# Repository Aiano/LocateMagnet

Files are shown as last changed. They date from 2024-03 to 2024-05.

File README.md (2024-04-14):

# 磁定位系统 LocateMagnet

## 简介

	这个项目来源于一个课设，要求使用AMR磁传感器对小磁铁进行三维空间定位，定位范围1cm x 1cm x 1cm，定位精度要求达到0.1mm。

	本项目采用了5x5 AMR磁传感器阵列，在远超课设要求的范围下，同时满足精度要求，此外还能实时检测，画出移动轨迹。

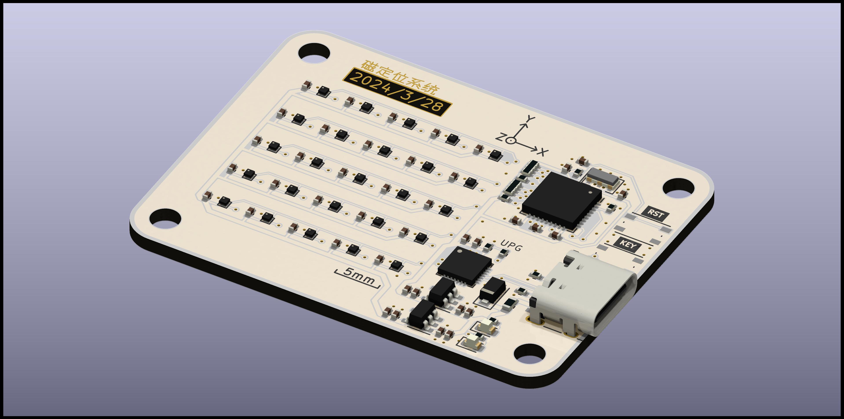
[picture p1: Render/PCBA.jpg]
PCBA


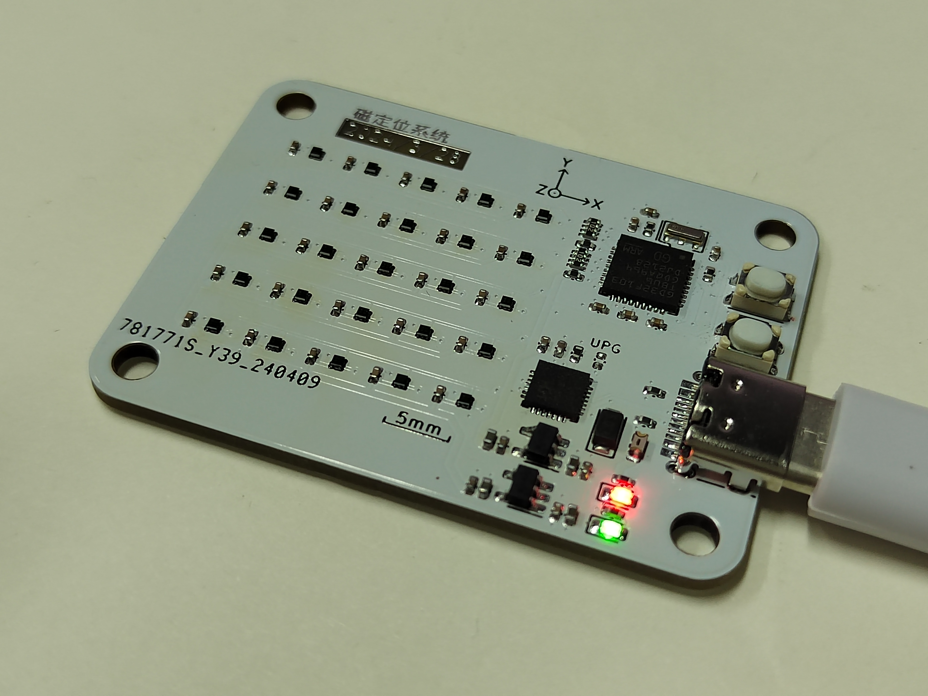
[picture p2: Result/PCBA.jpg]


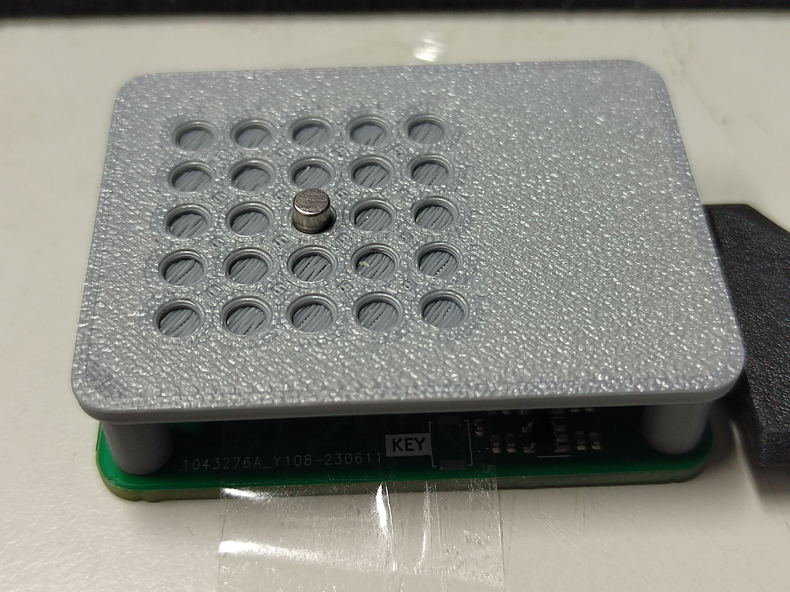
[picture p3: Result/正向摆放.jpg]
正向摆放


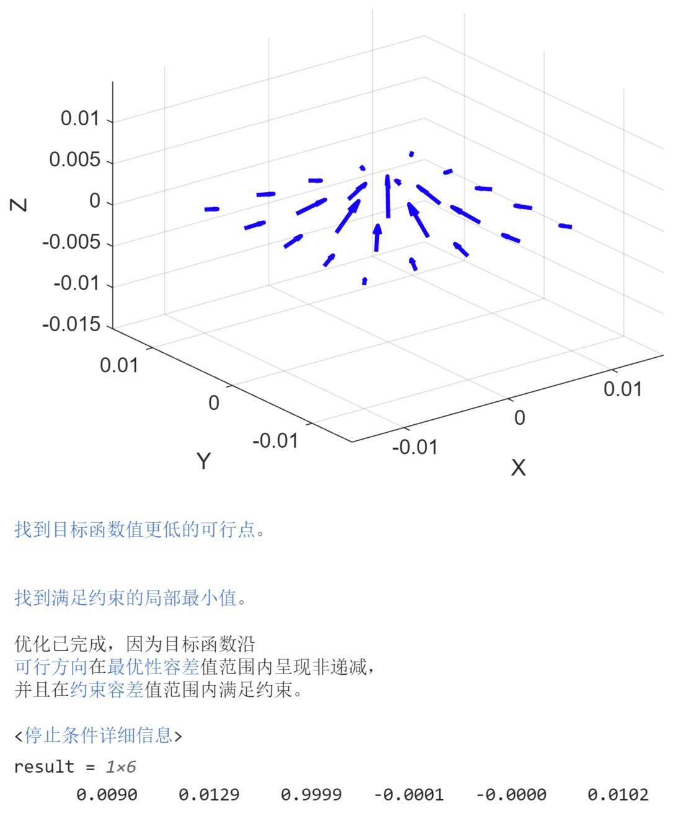
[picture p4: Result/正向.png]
正向


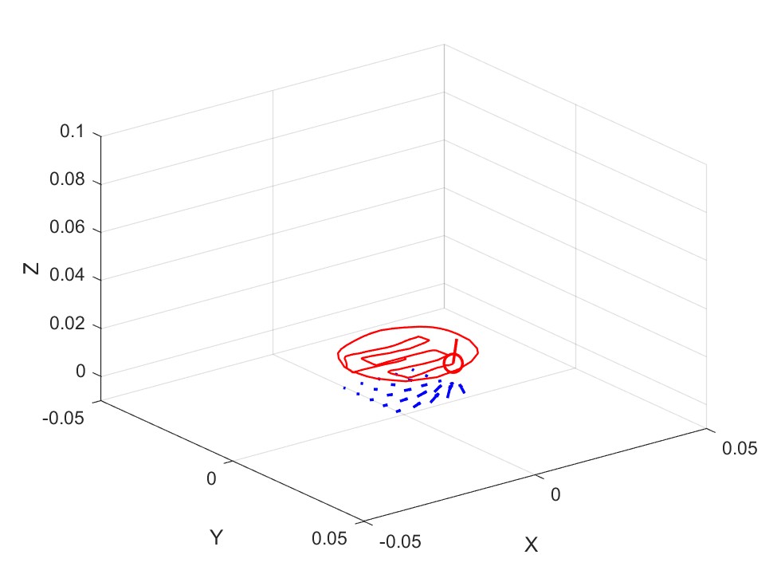
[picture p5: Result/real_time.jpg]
Real time


## 文件结构

- Firmware: STM32代码
- Hardware: PCB工程
- Mechanical: 测试架和磁铁胶囊的3D模型
- Result: 测试结果
- Software: MATLAB上位机代码
- Tools: WCHLINK固件、烧录器、配置器
- Render: 渲染图

## 运行环境

- Keil 5
- STM32CubeMX
- KiCAD 6
- MATLAB **2023b**

## 复刻流程

1. PCB投板：可以直接拿gerber压缩包去投板

2. 购买元件：bom文件夹里有元件清单

3. 焊接：建议使用回流焊，没有的可以用热风枪代替，建议**先焊接除传感器外的其他元件**，测试可用后，再焊接传感器。该芯片是WLP晶圆级封装，很小，可以先在焊盘上涂助焊剂，放上芯片，热风枪吹焊，同时在显微镜下观察，当芯片轻微移动归位时，用镊子轻轻推动，如果芯片被推后能够归位，说明焊接成功。

4. WCHLINK固件烧录：PCB板载一个WCHLINK，方便调试，先**短接**PCB上的**UPG焊盘**，连接PC，检测到设备后，使用**WCHISPTool**下载`WCHLINK_V02.03.bin`，然后把UPG焊盘断开，再次连接PC，初次烧录固件，WCHLINK处于RISC-V模式，打开WCH-LinkUtility，点Get获取当前Mode，切换成**WCH-LinkDAP-WINUSB**，点Set，配置好后WCHLINK会变成ARM模式，如果使用Keil能检测到stm32芯片就算成功

5. stm32固件烧录：正常使用Keil下载代码，调试器选择DAPLINK

    Optional：如果板载芯片是GD32，请安装`Tools/GigaDevice.GD32F10x_DFP.2.0.3.pack`，然后选择`..._GD32_Compatible`的Keil工程下载

6. 串口调试助手：使用DAPLINK自带的串口输出数据，如果传感器都正常，应该能读到U ··· V ··· W ···系列数据，不会有No Ack提示

7. 打印测试架： 注意测试架只能放入直径3mm的小磁铁

8. 打开`compute_NT.mlx`：串口号要改成自己的串口，逐块运行代码，先移开磁体，获得校准矩阵，然后放上磁体，填入磁铁真实位置，如果读到的是空矩阵，再运行两遍尝试，最后计算出N_T这个和磁铁磁化强度相关的常数

9. 打开`real_time.m`：注意MATLAB必须先定位到`real_time`文件夹，填入N_T常数，先移开磁体，运行，然后再放上磁铁，最开始会有点卡，连续运行就会变流畅

## 相关链接

> [Arm Keil | Devices](https://www.keil.arm.com/devices/)

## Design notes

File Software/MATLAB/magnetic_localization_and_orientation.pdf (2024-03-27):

## 磁定位定向算法仿真

基于单磁偶极子模型获取传感器读数

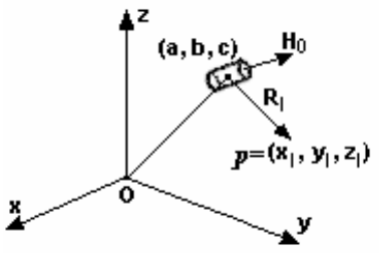
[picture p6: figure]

空间点 p 处的磁通密度（磁感应强度）：

- 永磁体长度 L
- 永磁体直径 b

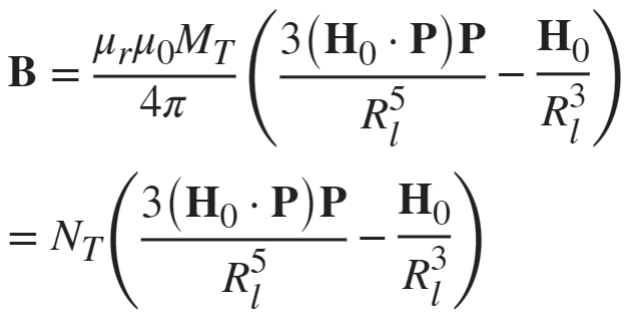
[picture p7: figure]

- 永磁体上下底面磁化强度 | (A/m)
•

•

- 永磁体位置指向空间点 p 的矢量 P
•

永磁体位置

•
永磁体朝向的归一化矢量

•

空间点

假设有 N 个传感器，第 l 个传感器的位置为 | ，那么，第 l 个传感器位置处的磁通密度可以表示

为：

三个正交项分别为：

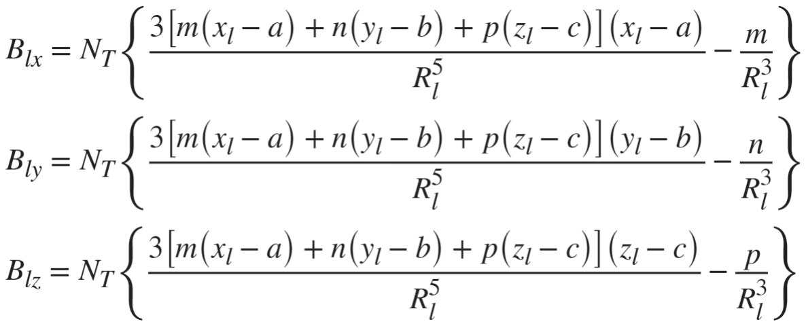
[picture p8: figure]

由于 是归一化矢量，有：

% 所有单位均采用国际单位制（SI)，坐标系采用右手系

mag_L = 0.003; % 永磁体圆柱长度
mag_b = 0.003; % 永磁体圆柱半径

N_T=1; % 系数
% 永磁体位置
a = 0; | % x
b = 0; | % y
c = 0.03; | % z
% 永磁体朝向
m = 0;
n = 0;
p = 1;
H_0 = [m;n;p];
H_0 = normalize(H_0,"norm"); % 归一化向量（按 L2 范数缩放）
% 传感器
sensor_n = 3; % 传感器行列数
sensor_interval = 0.01; % 传感器间隔
sensor_N = sensor_n^2; % 传感器数量 N sensor_pos = zeros(sensor_N,3); % 传感器位置 sensor_noise = 3e+02; % 传感器噪声
for i = 1:sensor_n % y
for j = 1:sensor_n % x
sensor_pos((i-1)*sensor_n + j,1)=((j-1)-(sensor_n-1)/ 2)*sensor_interval; % x sensor_pos((i-1)*sensor_n + j,2)=((i-1)-(sensor_n-1)/ 2)*sensor_interval; % y
sensor_pos((i-1)*sensor_n +
j,3)=0; | % z
end
end

Bl = zeros(sensor_N,3);
% 磁通密度
for i = 1:sensor_N
[Bl(i,1),Bl(i,2),Bl(i,3)] = MagneticFluxDensityComponent(N_T,H_0(1),H_0(2),H_0(3),a,b,c,sensor_pos(i,1),senso r_pos(i,2),sensor_pos(i,3),sensor_noise);
end

% 画出各个传感器获得的磁通密度矢量
figure;
quiver3(sensor_pos(:,1),sensor_pos(:,2),sensor_pos(:,3),Bl(:,1),Bl(:,2),Bl(:,3),' -b','LineWidth',2);
hold on;
% [X,Y,Z]=cylinder(mag_b/2);
% X=X+a;
% Y=Y+b;
% Z=Z*mag_L+c;
% s = surf(X,Y,Z);

plot3(a,b,c,'or','MarkerSize',10,'LineWidth',2); quiver3(a,b,c,m,n,p,0.01,'-r','LineWidth',2);

view([-38.7551 10.6989]);
xlabel('X');
ylabel('Y');
zlabel('Z');
legend('Sensor Data','real pos','real orient'); hold off;

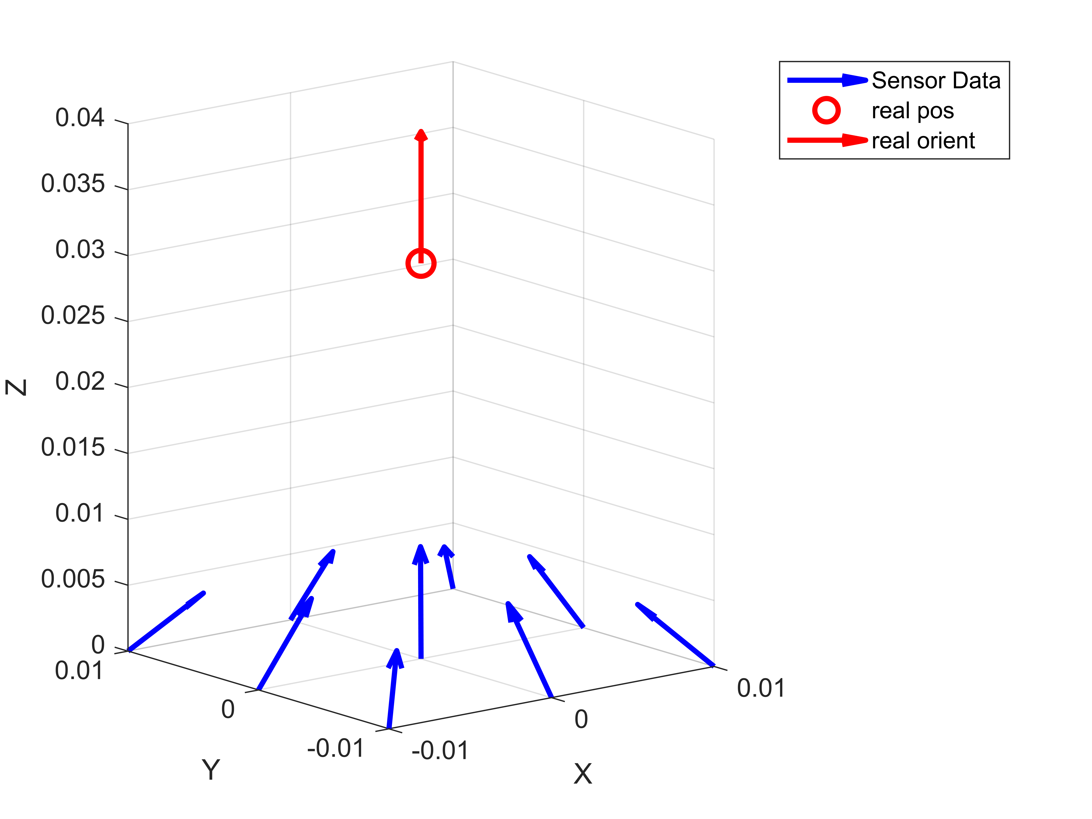
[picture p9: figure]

% test = target_function([0 0 1 0 0 0.03],sensor_pos,Bl,N_T) init = [0 0 1 0 0 0.05];
lb = []; % 上界
ub = []; % 下界
predict = lsqnonlin(@(param) target_function(param,sensor_pos,Bl,N_T),init,lb,ub, [],[],[],[],@nlcon)

可能存在局部最小值。满足约束。

fmincon 已停止，因为当前步长小于
步长容差值并且在约束容差值范围内满足约束。

<停止条件详细信息>
predict = 1×6
-0.0181 | -0.0616 | 0.9979 | -0.0002 | -0.0005 | 0.0301
% 比较磁铁真实位置与预测位置
figure;
plot3(a,b,c,'or','MarkerSize',10,'LineWidth',3);
hold on;
quiver3(a,b,c,m,n,p,0.01,'-r','LineWidth',3);

plot3(predict(4),predict(5),predict(6),'ob','MarkerSize',10,'LineWidth',3); quiver3(predict(4),predict(5),predict(6),predict(1),predict(2),predict(3),0.01,'--b','LineWidth',3);

legend('real pos','real orient','predict pos','predict orient');
view([-50.0849 8.8183]);
hold off;

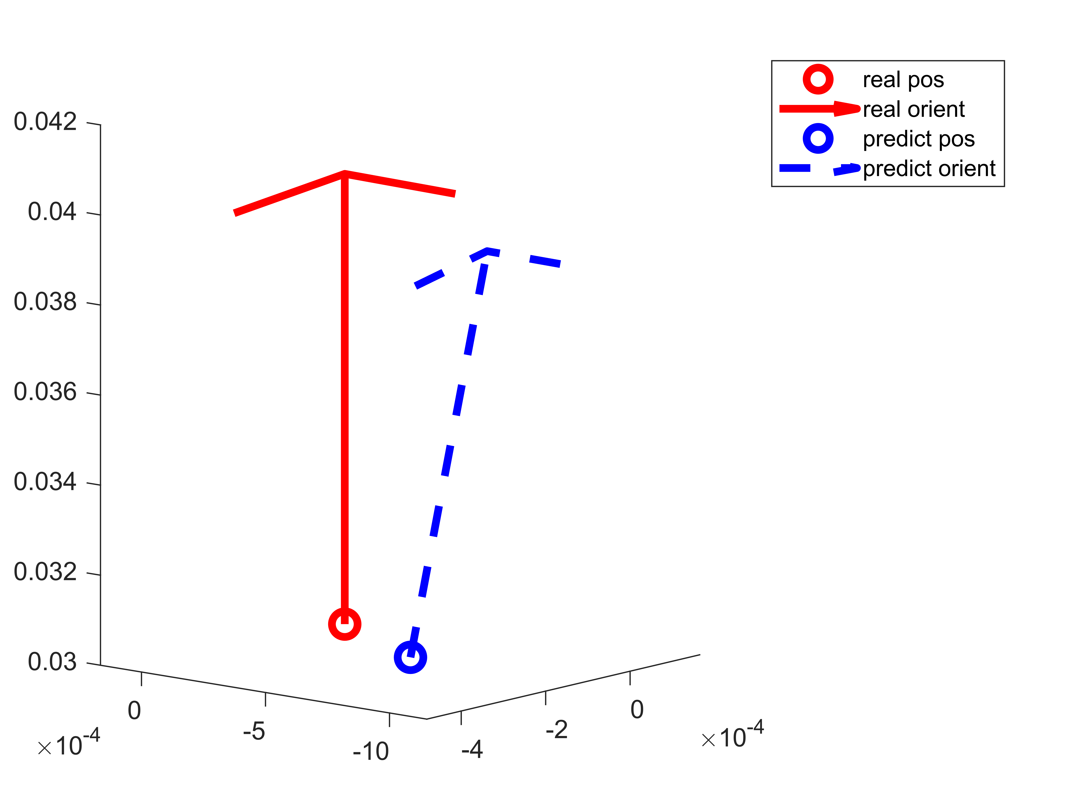
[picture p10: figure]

function [Blx, Bly, Blz] = MagneticFluxDensityComponent(N_T,m,n,p,a,b,c,x,y,z,noise)
rng default % 为了可重复性，设置默认随机数种子

Rl = sqrt((x-a)^2+(y-b)^2+(z-c)^2);
comm = 3*(m*(x-a)+n*(y-b)+p*(z-c));
Blx = N_T*((comm*(x-a))/(Rl^5)-m/(Rl^3)) + noise*randn; Bly = N_T*((comm*(y-b))/(Rl^5)-n/(Rl^3)) + noise*randn; Blz = N_T*((comm*(z-c))/(Rl^5)-p/(Rl^3)) + noise*randn; end

function F = target_function(param,sensor_pos,Bl,N_T) m = param(1);
n = param(2);
p = param(3);
a = param(4);
b = param(5);
c = param(6);
N = size(sensor_pos,1);
Bpre = zeros(N,3);
for i = 1:N
[Bpre(i,1),Bpre(i,2),Bpre(i,3)] = MagneticFluxDensityComponent(N_T,m,n,p,a,b,c,sensor_pos(i,1),sensor_pos(i,2),sens or_pos(i,3),0);
F((i-1)*3 + 1) = Bpre(i,1) - Bl(i,1);
F((i-1)*3 + 2) = Bpre(i,2) - Bl(i,2);
F((i-1)*3 + 3) = Bpre(i,3) - Bl(i,3); end

end

function [c,ceq] = nlcon(param) c = [];

m = param(1);
n = param(2);
p = param(3);
ceq = m^2 + n^2 + p^2 - 1; end

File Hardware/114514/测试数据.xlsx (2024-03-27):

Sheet: Beta版
0.0 | 0.0 | 0.0362 | -0.0054
0.0 | -0.5 | -0.13 | -0.4
1.0 | -0.5 | 0.94 | -0.33
1.0 | 1.0 | 0.94 | 0.99
-1.0 | -4.5 | -1.19 | -4.12
-1.0 | -2.0 | -0.99 | -1.71
-1.0 | 0.5 | -0.94 | 0.56
-1.5 | 1.5 | -1.32 | 1.61
-1.5 | 2.5 | -1.2 | 2.6
2.0 | 1.5 | 1.89 | 1.43
2.5 | 1.5 | 2.45 | 1.45
-2.5 | -2.5 | -2.51 | -2.15
3.0 | 1.5 | 2.84 | 1.39
3.0 | 2.0 | 2.92 | 1.78
3.0 | 2.5 | 2.87 | 2.23
-3.0 | -4.0 | -3.0 | -3.6
-3.0 | 3.0 | -2.73 | 3.05
3.5 | 2.5 | 3.36 | 2.41
3.5 | 3.0 | 3.46 | 2.84
3.5 | 3.5 | 3.52 | 3.32
3.5 | 4.0 | 3.57 | 3.78
3.5 | -2.5 | 3.19 | -2.39
4..0 | 4.0 | 3.90 | 3.70
4.0 | -1.0 | 3.72 | -1.03
4.0 | -2.0 | 3.67 | -1.97
4.0 | -3.5 | 3.63 | -3.29
-4.0 | 4.0 | -3.63 | 4.02
4.5 | 4.0 | 4.44 | 3.74
4.5 | 4.5 | 4.38 | 4.21
4.5 | 5.0 | 4.47 | 4.66
4.5 | -4.5 | 4.18 | -4.19
-4.5 | -3.5 | -4.4 | -3.01
5.0 | 5.0 | 4.76 | 4.51
-5.0 | 5.0 | -4.55 | 4.90
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

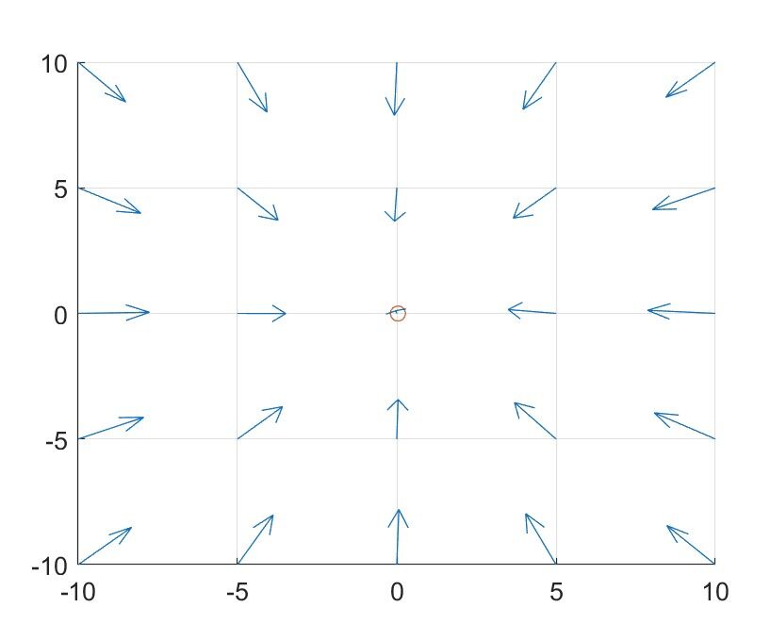
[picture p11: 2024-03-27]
Hardware/114514/PIC/0,0.jpg

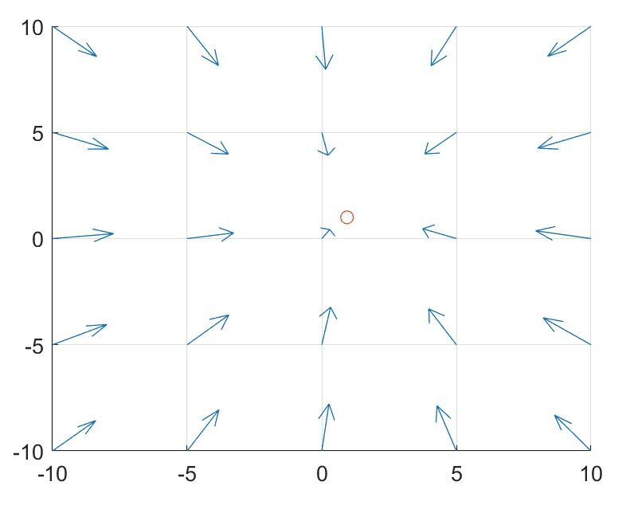
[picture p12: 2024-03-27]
Hardware/114514/PIC/1,1.jpg

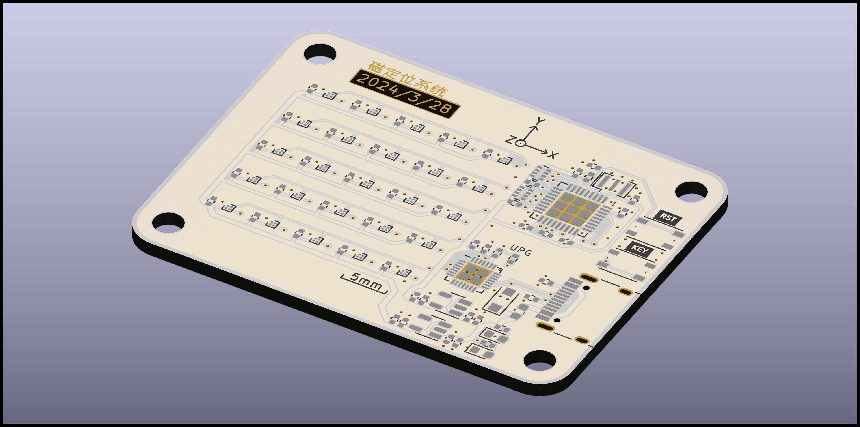
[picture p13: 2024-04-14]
Render/PCB.jpg

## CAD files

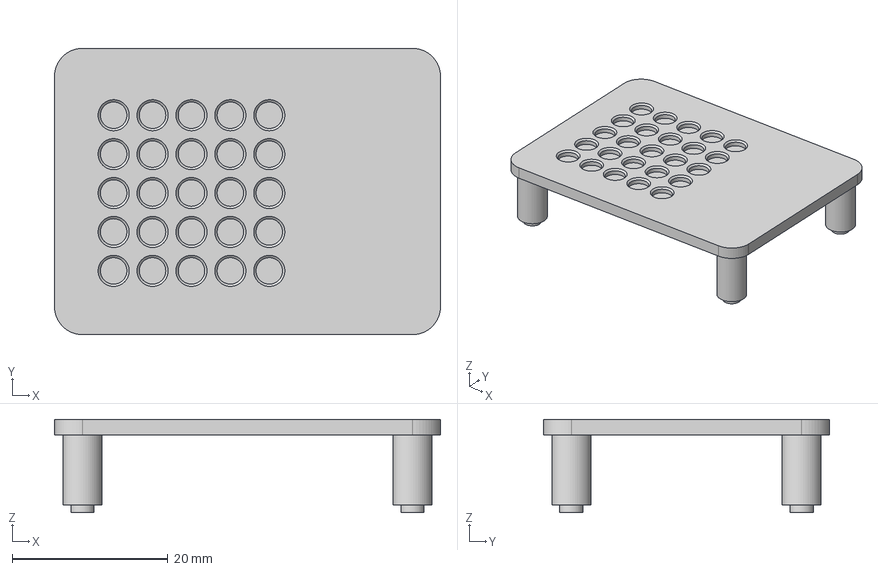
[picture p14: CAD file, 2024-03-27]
Mechanical/1mm高度测试架 v2.step
49.6 x 36.8 x 12.0 mm

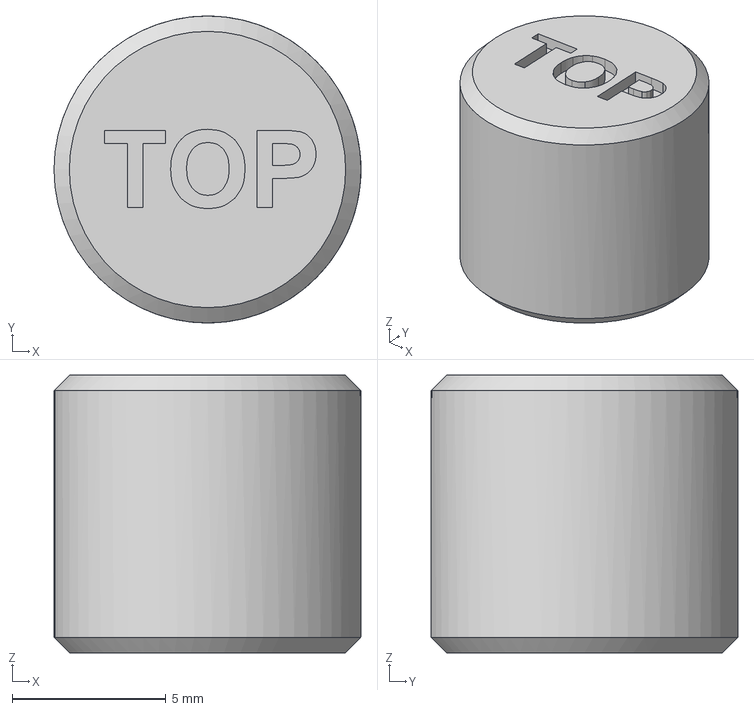
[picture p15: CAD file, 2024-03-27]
Mechanical/磁铁胶囊 v1.step
10.0 x 10.0 x 9.04 mm

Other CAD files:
Mechanical/磁铁胶囊 v1.3mf

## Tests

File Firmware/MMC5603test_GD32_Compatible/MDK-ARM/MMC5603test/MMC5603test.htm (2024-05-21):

# Static Call Graph for image MMC5603test\MMC5603test.axf

#<CALLGRAPH># ARM Linker, 6140002: Last Updated: Tue May 21 18:15:45 2024

### Maximum Stack Usage = 736 bytes + Unknown(Cycles, Untraceable Function Pointers)

### Call chain for Maximum Stack Depth:

main ⇒ readSensorData ⇒ i2cReadByte ⇒ puts ⇒ fputc ⇒ HAL_UART_Transmit ⇒ UART_WaitOnFlagUntilTimeout

### Mutually Recursive functions

- ADC1_2_IRQHandler ⇒ ADC1_2_IRQHandler
- BusFault_Handler ⇒ BusFault_Handler
- HardFault_Handler ⇒ HardFault_Handler
- MemManage_Handler ⇒ MemManage_Handler
- NMI_Handler ⇒ NMI_Handler
- UART_EndRxTransfer ⇒ UART_EndRxTransfer
- UsageFault_Handler ⇒ UsageFault_Handler
- UART_EndTxTransfer ⇒ UART_EndTxTransfer

### Function Pointers

- ADC1_2_IRQHandler from startup_stm32f103xb.o(.text) referenced from startup_stm32f103xb.o(RESET)
- BusFault_Handler from stm32f1xx_it.o(.text.BusFault_Handler) referenced from startup_stm32f103xb.o(RESET)
- CAN1_RX1_IRQHandler from startup_stm32f103xb.o(.text) referenced from startup_stm32f103xb.o(RESET)
- CAN1_SCE_IRQHandler from startup_stm32f103xb.o(.text) referenced from startup_stm32f103xb.o(RESET)
- DMA1_Channel1_IRQHandler from startup_stm32f103xb.o(.text) referenced from startup_stm32f103xb.o(RESET)
- DMA1_Channel2_IRQHandler from startup_stm32f103xb.o(.text) referenced from startup_stm32f103xb.o(RESET)
- DMA1_Channel3_IRQHandler from startup_stm32f103xb.o(.text) referenced from startup_stm32f103xb.o(RESET)
- DMA1_Channel4_IRQHandler from stm32f1xx_it.o(.text.DMA1_Channel4_IRQHandler) referenced from startup_stm32f103xb.o(RESET)
- DMA1_Channel5_IRQHandler from stm32f1xx_it.o(.text.DMA1_Channel5_IRQHandler) referenced from startup_stm32f103xb.o(RESET)
- DMA1_Channel6_IRQHandler from startup_stm32f103xb.o(.text) referenced from startup_stm32f103xb.o(RESET)
- DMA1_Channel7_IRQHandler from startup_stm32f103xb.o(.text) referenced from startup_stm32f103xb.o(RESET)
- DebugMon_Handler from stm32f1xx_it.o(.text.DebugMon_Handler) referenced from startup_stm32f103xb.o(RESET)
- EXTI0_IRQHandler from startup_stm32f103xb.o(.text) referenced from startup_stm32f103xb.o(RESET)
- EXTI15_10_IRQHandler from startup_stm32f103xb.o(.text) referenced from startup_stm32f103xb.o(RESET)
- EXTI1_IRQHandler from startup_stm32f103xb.o(.text) referenced from startup_stm32f103xb.o(RESET)
- EXTI2_IRQHandler from startup_stm32f103xb.o(.text) referenced from startup_stm32f103xb.o(RESET)
- EXTI3_IRQHandler from startup_stm32f103xb.o(.text) referenced from startup_stm32f103xb.o(RESET)
- EXTI4_IRQHandler from startup_stm32f103xb.o(.text) referenced from startup_stm32f103xb.o(RESET)
- EXTI9_5_IRQHandler from startup_stm32f103xb.o(.text) referenced from startup_stm32f103xb.o(RESET)
- FLASH_IRQHandler from startup_stm32f103xb.o(.text) referenced from startup_stm32f103xb.o(RESET)
- HAL_GPIO_Init from stm32f1xx_hal_gpio.o(.text.HAL_GPIO_Init) referenced from gpio.o(.text.MX_GPIO_Init)
- HAL_GPIO_WritePin from stm32f1xx_hal_gpio.o(.text.HAL_GPIO_WritePin) referenced from gpio.o(.text.MX_GPIO_Init)
- HAL_GPIO_WritePin from stm32f1xx_hal_gpio.o(.text.HAL_GPIO_WritePin) referenced from i2c_sw.o(.text.i2c_stop)
- HardFault_Handler from stm32f1xx_it.o(.text.HardFault_Handler) referenced from startup_stm32f103xb.o(RESET)
- I2C1_ER_IRQHandler from startup_stm32f103xb.o(.text) referenced from startup_stm32f103xb.o(RESET)
- I2C1_EV_IRQHandler from startup_stm32f103xb.o(.text) referenced from startup_stm32f103xb.o(RESET)
- I2C2_ER_IRQHandler from startup_stm32f103xb.o(.text) referenced from startup_stm32f103xb.o(RESET)
- I2C2_EV_IRQHandler from startup_stm32f103xb.o(.text) referenced from startup_stm32f103xb.o(RESET)
- MemManage_Handler from stm32f1xx_it.o(.text.MemManage_Handler) referenced from startup_stm32f103xb.o(RESET)
- NMI_Handler from stm32f1xx_it.o(.text.NMI_Handler) referenced from startup_stm32f103xb.o(RESET)
- PVD_IRQHandler from startup_stm32f103xb.o(.text) referenced from startup_stm32f103xb.o(RESET)
- PendSV_Handler from stm32f1xx_it.o(.text.PendSV_Handler) referenced from startup_stm32f103xb.o(RESET)
- RCC_IRQHandler from startup_stm32f103xb.o(.text) referenced from startup_stm32f103xb.o(RESET)
- RTC_Alarm_IRQHandler from startup_stm32f103xb.o(.text) referenced from startup_stm32f103xb.o(RESET)
- RTC_IRQHandler from startup_stm32f103xb.o(.text) referenced from startup_stm32f103xb.o(RESET)
- Reset_Handler from startup_stm32f103xb.o(.text) referenced from startup_stm32f103xb.o(RESET)
- SPI1_IRQHandler from startup_stm32f103xb.o(.text) referenced from startup_stm32f103xb.o(RESET)
- SPI2_IRQHandler from startup_stm32f103xb.o(.text) referenced from startup_stm32f103xb.o(RESET)
- SVC_Handler from stm32f1xx_it.o(.text.SVC_Handler) referenced from startup_stm32f103xb.o(RESET)
- SysTick_Handler from stm32f1xx_it.o(.text.SysTick_Handler) referenced from startup_stm32f103xb.o(RESET)
- SystemInit from system_stm32f1xx.o(.text.SystemInit) referenced from startup_stm32f103xb.o(.text)
- TAMPER_IRQHandler from startup_stm32f103xb.o(.text) referenced from startup_stm32f103xb.o(RESET)
- TIM1_BRK_IRQHandler from startup_stm32f103xb.o(.text) referenced from startup_stm32f103xb.o(RESET)
- TIM1_CC_IRQHandler from startup_stm32f103xb.o(.text) referenced from startup_stm32f103xb.o(RESET)
- TIM1_TRG_COM_IRQHandler from startup_stm32f103xb.o(.text) referenced from startup_stm32f103xb.o(RESET)
- TIM1_UP_IRQHandler from startup_stm32f103xb.o(.text) referenced from startup_stm32f103xb.o(RESET)
- TIM2_IRQHandler from stm32f1xx_it.o(.text.TIM2_IRQHandler) referenced from startup_stm32f103xb.o(RESET)
- TIM3_IRQHandler from startup_stm32f103xb.o(.text) referenced from startup_stm32f103xb.o(RESET)
- TIM4_IRQHandler from startup_stm32f103xb.o(.text) referenced from startup_stm32f103xb.o(RESET)
- UART_DMAAbortOnError from stm32f1xx_hal_uart.o(.text.UART_DMAAbortOnError) referenced from stm32f1xx_hal_uart.o(.text.HAL_UART_IRQHandler)
- UART_DMAError from stm32f1xx_hal_uart.o(.text.UART_DMAError) referenced from stm32f1xx_hal_uart.o(.text.HAL_UART_Transmit_DMA)
- UART_DMATransmitCplt from stm32f1xx_hal_uart.o(.text.UART_DMATransmitCplt) referenced from stm32f1xx_hal_uart.o(.text.HAL_UART_Transmit_DMA)
- UART_DMATxHalfCplt from stm32f1xx_hal_uart.o(.text.UART_DMATxHalfCplt) referenced from stm32f1xx_hal_uart.o(.text.HAL_UART_Transmit_DMA)
- USART1_IRQHandler from stm32f1xx_it.o(.text.USART1_IRQHandler) referenced from startup_stm32f103xb.o(RESET)
- USART2_IRQHandler from startup_stm32f103xb.o(.text) referenced from startup_stm32f103xb.o(RESET)
- USART3_IRQHandler from startup_stm32f103xb.o(.text) referenced from startup_stm32f103xb.o(RESET)
- USBWakeUp_IRQHandler from startup_stm32f103xb.o(.text) referenced from startup_stm32f103xb.o(RESET)
- USB_HP_CAN1_TX_IRQHandler from startup_stm32f103xb.o(.text) referenced from startup_stm32f103xb.o(RESET)
- USB_LP_CAN1_RX0_IRQHandler from startup_stm32f103xb.o(.text) referenced from startup_stm32f103xb.o(RESET)
- UsageFault_Handler from stm32f1xx_it.o(.text.UsageFault_Handler) referenced from startup_stm32f103xb.o(RESET)
- WWDG_IRQHandler from startup_stm32f103xb.o(.text) referenced from startup_stm32f103xb.o(RESET)
- __main from entry.o(.ARM.Collect$$$$00000000) referenced from startup_stm32f103xb.o(.text)
- _sputc from printf1.o(i._sputc) referenced from printf1.o(i.__0sprintf$1)
- delay_us from i2c_sw.o(.text.delay_us) referenced from i2c_sw.o(.text.i2c_stop)
- i2cWriteByte from i2c_sw.o(.text.i2cWriteByte) referenced from main.o(.text.sensorInit)
- main from main.o(.text.main) referenced from entry9a.o(.ARM.Collect$$$$0000000B)

### Global Symbols

__main (Thumb, 0 bytes, Stack size unknown bytes, entry.o(.ARM.Collect$$$$00000000))
[Address Reference Count : 1]

- startup_stm32f103xb.o(.text)

_main_stk (Thumb, 0 bytes, Stack size unknown bytes, entry2.o(.ARM.Collect$$$$00000001))

_main_scatterload (Thumb, 0 bytes, Stack size unknown bytes, entry5.o(.ARM.Collect$$$$00000004))

[Calls]

- >> __scatterload

__main_after_scatterload (Thumb, 0 bytes, Stack size unknown bytes, entry5.o(.ARM.Collect$$$$00000004))

[Called By]

- >> __scatterload

_main_clock (Thumb, 0 bytes, Stack size unknown bytes, entry7b.o(.ARM.Collect$$$$00000008))

_main_cpp_init (Thumb, 0 bytes, Stack size unknown bytes, entry8b.o(.ARM.Collect$$$$0000000A))

_main_init (Thumb, 0 bytes, Stack size unknown bytes, entry9a.o(.ARM.Collect$$$$0000000B))

__rt_final_cpp (Thumb, 0 bytes, Stack size unknown bytes, entry10a.o(.ARM.Collect$$$$0000000D))

__rt_final_exit (Thumb, 0 bytes, Stack size unknown bytes, entry11a.o(.ARM.Collect$$$$0000000F))

Reset_Handler (Thumb, 8 bytes, Stack size 0 bytes, startup_stm32f103xb.o(.text))
[Address Reference Count : 1]

- startup_stm32f103xb.o(RESET)

ADC1_2_IRQHandler (Thumb, 0 bytes, Stack size 0 bytes, startup_stm32f103xb.o(.text))

[Calls]

- >> ADC1_2_IRQHandler

[Called By]

- >> ADC1_2_IRQHandler

[Address Reference Count : 1]

- startup_stm32f103xb.o(RESET)

CAN1_RX1_IRQHandler (Thumb, 0 bytes, Stack size 0 bytes, startup_stm32f103xb.o(.text))
[Address Reference Count : 1]

- startup_stm32f103xb.o(RESET)

CAN1_SCE_IRQHandler (Thumb, 0 bytes, Stack size 0 bytes, startup_stm32f103xb.o(.text))
[Address Reference Count : 1]

- startup_stm32f103xb.o(RESET)

DMA1_Channel1_IRQHandler (Thumb, 0 bytes, Stack size 0 bytes, startup_stm32f103xb.o(.text))
[Address Reference Count : 1]

- startup_stm32f103xb.o(RESET)

DMA1_Channel2_IRQHandler (Thumb, 0 bytes, Stack size 0 bytes, startup_stm32f103xb.o(.text))
[Address Reference Count : 1]

- startup_stm32f103xb.o(RESET)

DMA1_Channel3_IRQHandler (Thumb, 0 bytes, Stack size 0 bytes, startup_stm32f103xb.o(.text))
[Address Reference Count : 1]

- startup_stm32f103xb.o(RESET)

DMA1_Channel6_IRQHandler (Thumb, 0 bytes, Stack size 0 bytes, startup_stm32f103xb.o(.text))
[Address Reference Count : 1]

- startup_stm32f103xb.o(RESET)

DMA1_Channel7_IRQHandler (Thumb, 0 bytes, Stack size 0 bytes, startup_stm32f103xb.o(.text))
[Address Reference Count : 1]

- startup_stm32f103xb.o(RESET)

EXTI0_IRQHandler (Thumb, 0 bytes, Stack size 0 bytes, startup_stm32f103xb.o(.text))
[Address Reference Count : 1]

- startup_stm32f103xb.o(RESET)

EXTI15_10_IRQHandler (Thumb, 0 bytes, Stack size 0 bytes, startup_stm32f103xb.o(.text))
[Address Reference Count : 1]

- startup_stm32f103xb.o(RESET)

EXTI1_IRQHandler (Thumb, 0 bytes, Stack size 0 bytes, startup_stm32f103xb.o(.text))
[Address Reference Count : 1]

- startup_stm32f103xb.o(RESET)

EXTI2_IRQHandler (Thumb, 0 bytes, Stack size 0 bytes, startup_stm32f103xb.o(.text))
[Address Reference Count : 1]

- startup_stm32f103xb.o(RESET)

EXTI3_IRQHandler (Thumb, 0 bytes, Stack size 0 bytes, startup_stm32f103xb.o(.text))
[Address Reference Count : 1]

- startup_stm32f103xb.o(RESET)

EXTI4_IRQHandler (Thumb, 0 bytes, Stack size 0 bytes, startup_stm32f103xb.o(.text))
[Address Reference Count : 1]

- startup_stm32f103xb.o(RESET)

EXTI9_5_IRQHandler (Thumb, 0 bytes, Stack size 0 bytes, startup_stm32f103xb.o(.text))
[Address Reference Count : 1]

- startup_stm32f103xb.o(RESET)

FLASH_IRQHandler (Thumb, 0 bytes, Stack size 0 bytes, startup_stm32f103xb.o(.text))
[Address Reference Count : 1]

- startup_stm32f103xb.o(RESET)

I2C1_ER_IRQHandler (Thumb, 0 bytes, Stack size 0 bytes, startup_stm32f103xb.o(.text))
[Address Reference Count : 1]

- startup_stm32f103xb.o(RESET)

I2C1_EV_IRQHandler (Thumb, 0 bytes, Stack size 0 bytes, startup_stm32f103xb.o(.text))
[Address Reference Count : 1]

- startup_stm32f103xb.o(RESET)

I2C2_ER_IRQHandler (Thumb, 0 bytes, Stack size 0 bytes, startup_stm32f103xb.o(.text))
[Address Reference Count : 1]

- startup_stm32f103xb.o(RESET)

I2C2_EV_IRQHandler (Thumb, 0 bytes, Stack size 0 bytes, startup_stm32f103xb.o(.text))
[Address Reference Count : 1]

- startup_stm32f103xb.o(RESET)

PVD_IRQHandler (Thumb, 0 bytes, Stack size 0 bytes, startup_stm32f103xb.o(.text))
[Address Reference Count : 1]

- startup_stm32f103xb.o(RESET)

RCC_IRQHandler (Thumb, 0 bytes, Stack size 0 bytes, startup_stm32f103xb.o(.text))
[Address Reference Count : 1]

- startup_stm32f103xb.o(RESET)

RTC_Alarm_IRQHandler (Thumb, 0 bytes, Stack size 0 bytes, startup_stm32f103xb.o(.text))
[Address Reference Count : 1]

- startup_stm32f103xb.o(RESET)

RTC_IRQHandler (Thumb, 0 bytes, Stack size 0 bytes, startup_stm32f103xb.o(.text))
[Address Reference Count : 1]

- startup_stm32f103xb.o(RESET)

SPI1_IRQHandler (Thumb, 0 bytes, Stack size 0 bytes, startup_stm32f103xb.o(.text))
[Address Reference Count : 1]

- startup_stm32f103xb.o(RESET)

SPI2_IRQHandler (Thumb, 0 bytes, Stack size 0 bytes, startup_stm32f103xb.o(.text))
[Address Reference Count : 1]

- startup_stm32f103xb.o(RESET)

TAMPER_IRQHandler (Thumb, 0 bytes, Stack size 0 bytes, startup_stm32f103xb.o(.text))
[Address Reference Count : 1]

- startup_stm32f103xb.o(RESET)

TIM1_BRK_IRQHandler (Thumb, 0 bytes, Stack size 0 bytes, startup_stm32f103xb.o(.text))
[Address Reference Count : 1]

- startup_stm32f103xb.o(RESET)

TIM1_CC_IRQHandler (Thumb, 0 bytes, Stack size 0 bytes, startup_stm32f103xb.o(.text))
[Address Reference Count : 1]

- startup_stm32f103xb.o(RESET)

TIM1_TRG_COM_IRQHandler (Thumb, 0 bytes, Stack size 0 bytes, startup_stm32f103xb.o(.text))
[Address Reference Count : 1]

- startup_stm32f103xb.o(RESET)

TIM1_UP_IRQHandler (Thumb, 0 bytes, Stack size 0 bytes, startup_stm32f103xb.o(.text))
[Address Reference Count : 1]

- startup_stm32f103xb.o(RESET)

TIM3_IRQHandler (Thumb, 0 bytes, Stack size 0 bytes, startup_stm32f103xb.o(.text))
[Address Reference Count : 1]

- startup_stm32f103xb.o(RESET)

TIM4_IRQHandler (Thumb, 0 bytes, Stack size 0 bytes, startup_stm32f103xb.o(.text))
[Address Reference Count : 1]

- startup_stm32f103xb.o(RESET)

USART2_IRQHandler (Thumb, 0 bytes, Stack size 0 bytes, startup_stm32f103xb.o(.text))
[Address Reference Count : 1]

- startup_stm32f103xb.o(RESET)

USART3_IRQHandler (Thumb, 0 bytes, Stack size 0 bytes, startup_stm32f103xb.o(.text))
[Address Reference Count : 1]

- startup_stm32f103xb.o(RESET)

USBWakeUp_IRQHandler (Thumb, 0 bytes, Stack size 0 bytes, startup_stm32f103xb.o(.text))
[Address Reference Count : 1]

- startup_stm32f103xb.o(RESET)

USB_HP_CAN1_TX_IRQHandler (Thumb, 0 bytes, Stack size 0 bytes, startup_stm32f103xb.o(.text))
[Address Reference Count : 1]

- startup_stm32f103xb.o(RESET)

USB_LP_CAN1_RX0_IRQHandler (Thumb, 0 bytes, Stack size 0 bytes, startup_stm32f103xb.o(.text))
[Address Reference Count : 1]

- startup_stm32f103xb.o(RESET)

WWDG_IRQHandler (Thumb, 0 bytes, Stack size 0 bytes, startup_stm32f103xb.o(.text))
[Address Reference Count : 1]

- startup_stm32f103xb.o(RESET)

__aeabi_memset (Thumb, 14 bytes, Stack size 0 bytes, memseta.o(.text), UNUSED)

[Called By]

- >> _memset$wrapper
- >> __aeabi_memclr

__aeabi_memset4 (Thumb, 0 bytes, Stack size 0 bytes, memseta.o(.text), UNUSED)

__aeabi_memset8 (Thumb, 0 bytes, Stack size 0 bytes, memseta.o(.text), UNUSED)

__aeabi_memclr (Thumb, 4 bytes, Stack size 0 bytes, memseta.o(.text), UNUSED)

[Calls]

- >> __aeabi_memset

__aeabi_memclr4 (Thumb, 0 bytes, Stack size 0 bytes, memseta.o(.text))

[Called By]

- >> SystemClock_Config

__aeabi_memclr8 (Thumb, 0 bytes, Stack size 0 bytes, memseta.o(.text), UNUSED)

_memset$wrapper (Thumb, 18 bytes, Stack size 8 bytes, memseta.o(.text), UNUSED)

[Calls]

- >> __aeabi_memset

strlen (Thumb, 14 bytes, Stack size 0 bytes, strlen.o(.text))

[Called By]

- >> main

__aeabi_uidiv (Thumb, 0 bytes, Stack size 12 bytes, uidiv.o(.text), UNUSED)

__aeabi_uidivmod (Thumb, 44 bytes, Stack size 12 bytes, uidiv.o(.text), UNUSED)

[Called By]

- >> _printf_core

__scatterload (Thumb, 28 bytes, Stack size 0 bytes, init.o(.text))

[Calls]

- >> __main_after_scatterload

[Called By]

- >> _main_scatterload

__scatterload_rt2 (Thumb, 0 bytes, Stack size 0 bytes, init.o(.text), UNUSED)

__decompress (Thumb, 0 bytes, Stack size unknown bytes, __dclz77c.o(.text), UNUSED)

__decompress2 (Thumb, 94 bytes, Stack size unknown bytes, __dclz77c.o(.text), UNUSED)

BusFault_Handler (Thumb, 2 bytes, Stack size 0 bytes, stm32f1xx_it.o(.text.BusFault_Handler))

[Calls]

- >> BusFault_Handler

[Called By]

- >> BusFault_Handler

[Address Reference Count : 1]

- startup_stm32f103xb.o(RESET)

DMA1_Channel4_IRQHandler (Thumb, 12 bytes, Stack size 0 bytes, stm32f1xx_it.o(.text.DMA1_Channel4_IRQHandler))

[Stack]

- Max Depth = 16
- Call Chain = DMA1_Channel4_IRQHandler ⇒ HAL_DMA_IRQHandler

[Calls]

- >> HAL_DMA_IRQHandler

[Address Reference Count : 1]

- startup_stm32f103xb.o(RESET)

DMA1_Channel5_IRQHandler (Thumb, 12 bytes, Stack size 0 bytes, stm32f1xx_it.o(.text.DMA1_Channel5_IRQHandler))

[Stack]

- Max Depth = 16
- Call Chain = DMA1_Channel5_IRQHandler ⇒ HAL_DMA_IRQHandler

[Calls]

- >> HAL_DMA_IRQHandler

[Address Reference Count : 1]

- startup_stm32f103xb.o(RESET)

DebugMon_Handler (Thumb, 2 bytes, Stack size 0 bytes, stm32f1xx_it.o(.text.DebugMon_Handler))
[Address Reference Count : 1]

- startup_stm32f103xb.o(RESET)

Error_Handler (Thumb, 8 bytes, Stack size 0 bytes, main.o(.text.Error_Handler))

[Called By]

- >> HAL_UART_MspInit
- >> MX_USART1_UART_Init
- >> MX_TIM2_Init
- >> MX_TIM1_Init

HAL_DMA_Abort (Thumb, 64 bytes, Stack size 8 bytes, stm32f1xx_hal_dma.o(.text.HAL_DMA_Abort))

[Stack]

- Max Depth = 8
- Call Chain = HAL_DMA_Abort

[Called By]

- >> HAL_UART_IRQHandler

HAL_DMA_Abort_IT (Thumb, 136 bytes, Stack size 16 bytes, stm32f1xx_hal_dma.o(.text.HAL_DMA_Abort_IT))

[Stack]

- Max Depth = 16
- Call Chain = HAL_DMA_Abort_IT

[Called By]

- >> HAL_UART_IRQHandler

HAL_DMA_IRQHandler (Thumb, 312 bytes, Stack size 16 bytes, stm32f1xx_hal_dma.o(.text.HAL_DMA_IRQHandler))

[Stack]

- Max Depth = 16
- Call Chain = HAL_DMA_IRQHandler

[Called By]

- >> DMA1_Channel5_IRQHandler
- >> DMA1_Channel4_IRQHandler

HAL_DMA_Init (Thumb, 108 bytes, Stack size 28 bytes, stm32f1xx_hal_dma.o(.text.HAL_DMA_Init))

[Stack]

- Max Depth = 28
- Call Chain = HAL_DMA_Init

[Called By]

- >> HAL_UART_MspInit

HAL_DMA_Start_IT (Thumb, 102 bytes, Stack size 16 bytes, stm32f1xx_hal_dma.o(.text.HAL_DMA_Start_IT))

[Stack]

- Max Depth = 36
- Call Chain = HAL_DMA_Start_IT ⇒ DMA_SetConfig

[Calls]

- >> DMA_SetConfig

[Called By]

- >> HAL_UART_Transmit_DMA

HAL_GPIO_Init (Thumb, 412 bytes, Stack size 44 bytes, stm32f1xx_hal_gpio.o(.text.HAL_GPIO_Init))

[Stack]

- Max Depth = 44
- Call Chain = HAL_GPIO_Init

[Called By]

- >> HAL_UART_MspInit

[Address Reference Count : 1]

- gpio.o(.text.MX_GPIO_Init)

HAL_GPIO_ReadPin (Thumb, 10 bytes, Stack size 0 bytes, stm32f1xx_hal_gpio.o(.text.HAL_GPIO_ReadPin))

[Called By]

- >> i2c_wit_ack
- >> i2c_read

HAL_GPIO_TogglePin (Thumb, 16 bytes, Stack size 0 bytes, stm32f1xx_hal_gpio.o(.text.HAL_GPIO_TogglePin))

[Called By]

- >> main

HAL_GPIO_WritePin (Thumb, 10 bytes, Stack size 0 bytes, stm32f1xx_hal_gpio.o(.text.HAL_GPIO_WritePin))

[Called By]

- >> i2c_wit_ack
- >> i2c_send
- >> i2c_read

[Address Reference Count : 2]

- i2c_sw.o(.text.i2c_stop)
- gpio.o(.text.MX_GPIO_Init)

HAL_GetTick (Thumb, 8 bytes, Stack size 0 bytes, stm32f1xx_hal.o(.text.HAL_GetTick))

[Called By]

- >> HAL_UART_Transmit
- >> HAL_RCC_OscConfig
- >> HAL_RCC_ClockConfig
- >> UART_WaitOnFlagUntilTimeout

HAL_IncTick (Thumb, 20 bytes, Stack size 0 bytes, stm32f1xx_hal.o(.text.HAL_IncTick))

[Called By]

- >> SysTick_Handler

HAL_Init (Thumb, 32 bytes, Stack size 8 bytes, stm32f1xx_hal.o(.text.HAL_Init))

[Stack]

- Max Depth = 48
- Call Chain = HAL_Init ⇒ HAL_InitTick ⇒ HAL_NVIC_SetPriority ⇒ __NVIC_SetPriority

[Calls]

- >> HAL_MspInit
- >> HAL_NVIC_SetPriorityGrouping
- >> HAL_InitTick

[Called By]

- >> main

HAL_InitTick (Thumb, 60 bytes, Stack size 16 bytes, stm32f1xx_hal.o(.text.HAL_InitTick))

[Stack]

- Max Depth = 40
- Call Chain = HAL_InitTick ⇒ HAL_NVIC_SetPriority ⇒ __NVIC_SetPriority

[Calls]

- >> HAL_NVIC_SetPriority
- >> HAL_SYSTICK_Config

[Called By]

- >> HAL_RCC_ClockConfig
- >> HAL_Init

HAL_MspInit (Thumb, 64 bytes, Stack size 8 bytes, stm32f1xx_hal_msp.o(.text.HAL_MspInit))

[Stack]

- Max Depth = 8
- Call Chain = HAL_MspInit

[Called By]

- >> HAL_Init

HAL_NVIC_EnableIRQ (Thumb, 28 bytes, Stack size 0 bytes, stm32f1xx_hal_cortex.o(.text.HAL_NVIC_EnableIRQ))

[Called By]

- >> HAL_UART_MspInit
- >> HAL_TIM_Base_MspInit
- >> MX_DMA_Init

HAL_NVIC_SetPriority (Thumb, 56 bytes, Stack size 16 bytes, stm32f1xx_hal_cortex.o(.text.HAL_NVIC_SetPriority))

[Stack]

- Max Depth = 24
- Call Chain = HAL_NVIC_SetPriority ⇒ __NVIC_SetPriority

[Calls]

- >> __NVIC_SetPriority

[Called By]

- >> HAL_UART_MspInit
- >> HAL_TIM_Base_MspInit
- >> MX_DMA_Init
- >> HAL_InitTick

HAL_NVIC_SetPriorityGrouping (Thumb, 32 bytes, Stack size 0 bytes, stm32f1xx_hal_cortex.o(.text.HAL_NVIC_SetPriorityGrouping))

[Called By]

- >> HAL_Init

HAL_RCC_ClockConfig (Thumb, 312 bytes, Stack size 32 bytes, stm32f1xx_hal_rcc.o(.text.HAL_RCC_ClockConfig))

[Stack]

- Max Depth = 72
- Call Chain = HAL_RCC_ClockConfig ⇒ HAL_InitTick ⇒ HAL_NVIC_SetPriority ⇒ __NVIC_SetPriority

[Calls]

- >> HAL_RCC_GetSysClockFreq
- >> HAL_InitTick
- >> HAL_GetTick

[Called By]

- >> SystemClock_Config

HAL_RCC_GetPCLK1Freq (Thumb, 20 bytes, Stack size 0 bytes, stm32f1xx_hal_rcc.o(.text.HAL_RCC_GetPCLK1Freq))

[Called By]

- >> UART_SetConfig

HAL_RCC_GetPCLK2Freq (Thumb, 28 bytes, Stack size 0 bytes, stm32f1xx_hal_rcc.o(.text.HAL_RCC_GetPCLK2Freq))

[Called By]

- >> UART_SetConfig

HAL_RCC_GetSysClockFreq (Thumb, 84 bytes, Stack size 8 bytes, stm32f1xx_hal_rcc.o(.text.HAL_RCC_GetSysClockFreq))

[Stack]

- Max Depth = 8
- Call Chain = HAL_RCC_GetSysClockFreq

[Called By]

- >> HAL_RCC_ClockConfig

HAL_RCC_OscConfig (Thumb, 820 bytes, Stack size 32 bytes, stm32f1xx_hal_rcc.o(.text.HAL_RCC_OscConfig))

[Stack]

- Max Depth = 32
- Call Chain = HAL_RCC_OscConfig

[Calls]

- >> HAL_GetTick

[Called By]

- >> SystemClock_Config

HAL_SYSTICK_Config (Thumb, 40 bytes, Stack size 0 bytes, stm32f1xx_hal_cortex.o(.text.HAL_SYSTICK_Config))

[Called By]

- >> HAL_InitTick

HAL_TIMEx_BreakCallback (Thumb, 2 bytes, Stack size 0 bytes, stm32f1xx_hal_tim_ex.o(.text.HAL_TIMEx_BreakCallback))

[Called By]

- >> HAL_TIM_IRQHandler

HAL_TIMEx_CommutCallback (Thumb, 2 bytes, Stack size 0 bytes, stm32f1xx_hal_tim_ex.o(.text.HAL_TIMEx_CommutCallback))

[Called By]

- >> HAL_TIM_IRQHandler

HAL_TIMEx_MasterConfigSynchronization (Thumb, 92 bytes, Stack size 8 bytes, stm32f1xx_hal_tim_ex.o(.text.HAL_TIMEx_MasterConfigSynchronization))

[Stack]

- Max Depth = 8
- Call Chain = HAL_TIMEx_MasterConfigSynchronization

[Called By]

- >> MX_TIM2_Init
- >> MX_TIM1_Init

HAL_TIM_Base_Init (Thumb, 88 bytes, Stack size 8 bytes, stm32f1xx_hal_tim.o(.text.HAL_TIM_Base_Init))

[Stack]

- Max Depth = 48
- Call Chain = HAL_TIM_Base_Init ⇒ HAL_TIM_Base_MspInit ⇒ HAL_NVIC_SetPriority ⇒ __NVIC_SetPriority

[Calls]

- >> HAL_TIM_Base_MspInit
- >> TIM_Base_SetConfig

[Called By]

- >> MX_TIM2_Init
- >> MX_TIM1_Init

HAL_TIM_Base_MspInit (Thumb, 84 bytes, Stack size 16 bytes, tim.o(.text.HAL_TIM_Base_MspInit))

[Stack]

- Max Depth = 40
- Call Chain = HAL_TIM_Base_MspInit ⇒ HAL_NVIC_SetPriority ⇒ __NVIC_SetPriority

[Calls]

- >> HAL_NVIC_SetPriority
- >> HAL_NVIC_EnableIRQ

[Called By]

- >> HAL_TIM_Base_Init

HAL_TIM_Base_Start (Thumb, 80 bytes, Stack size 0 bytes, stm32f1xx_hal_tim.o(.text.HAL_TIM_Base_Start))

[Called By]

- >> main

HAL_TIM_ConfigClockSource (Thumb, 246 bytes, Stack size 8 bytes, stm32f1xx_hal_tim.o(.text.HAL_TIM_ConfigClockSource))

[Stack]

- Max Depth = 16
- Call Chain = HAL_TIM_ConfigClockSource ⇒ TIM_TI2_ConfigInputStage

[Calls]

- >> TIM_TI2_ConfigInputStage
- >> TIM_TI1_ConfigInputStage

[Called By]

- >> MX_TIM2_Init
- >> MX_TIM1_Init

HAL_TIM_IC_CaptureCallback (Thumb, 2 bytes, Stack size 0 bytes, stm32f1xx_hal_tim.o(.text.HAL_TIM_IC_CaptureCallback))

[Called By]

- >> HAL_TIM_IRQHandler

HAL_TIM_IRQHandler (Thumb, 364 bytes, Stack size 8 bytes, stm32f1xx_hal_tim.o(.text.HAL_TIM_IRQHandler))

[Stack]

- Max Depth = 8
- Call Chain = HAL_TIM_IRQHandler

[Calls]
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

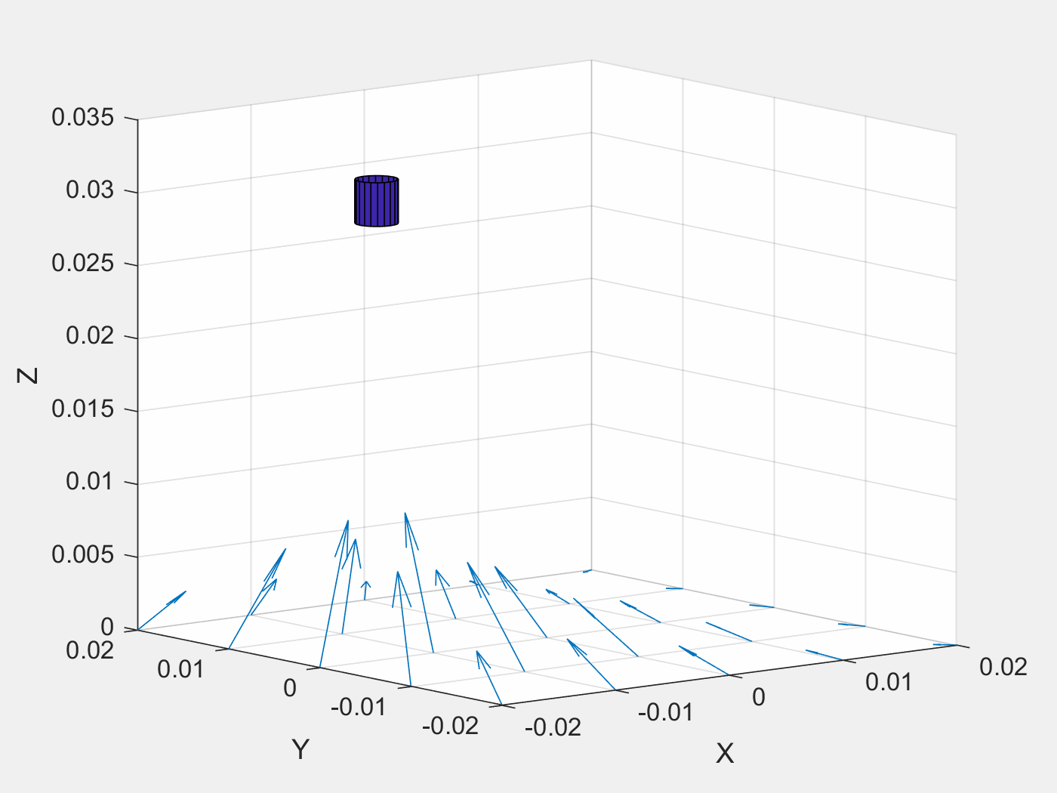
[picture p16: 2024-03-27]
Software/MATLAB/test.gif

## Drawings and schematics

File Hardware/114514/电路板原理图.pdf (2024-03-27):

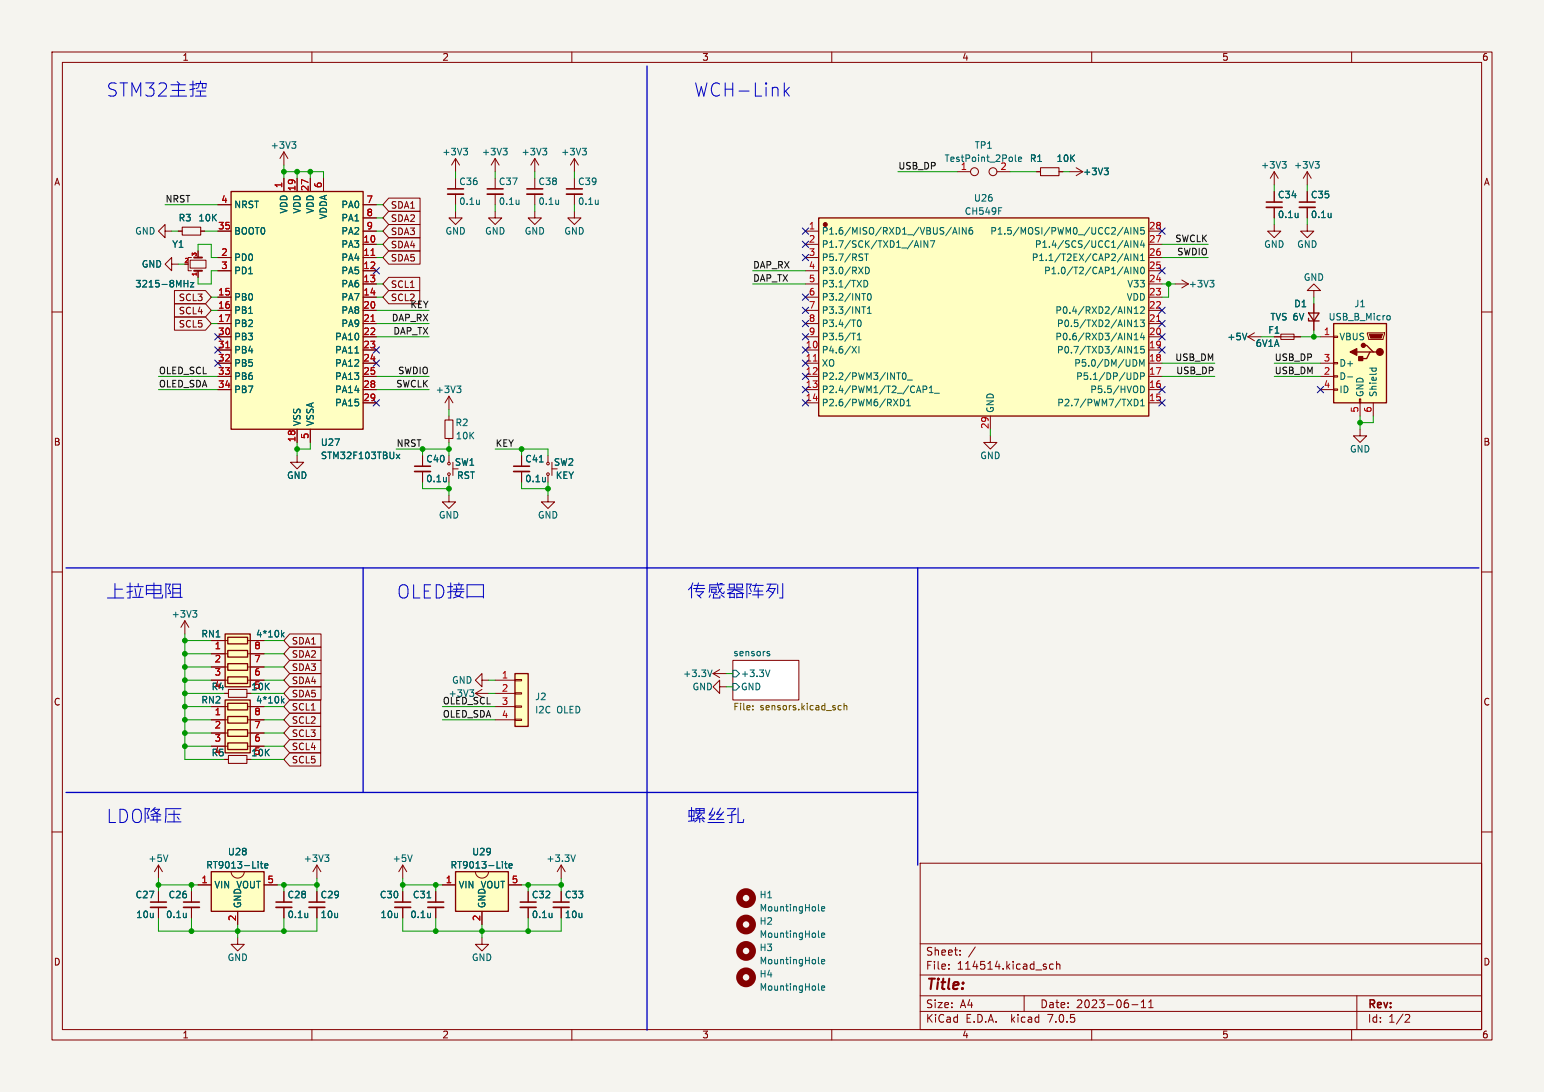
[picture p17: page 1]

1 PA3 10 PA4 11 PA5 12 PA6 13 PA7 14 PB0 15 PB1 16 PB2 17 VSS 18 VDD 19 PD0 2 PA8 20 PA9 21 PA10 22 PA11 23 PA12 24 PA13 25 VDD 27 PA14 28 PA15 29 PD1 3 PB3 30 PB4 31 PB5 32 PB6 33 PB7 34 BOOT0 35 NRST 4 VSSA

Id: 1/2 Title: File: 114514.kicad_sch Sheet: / GND

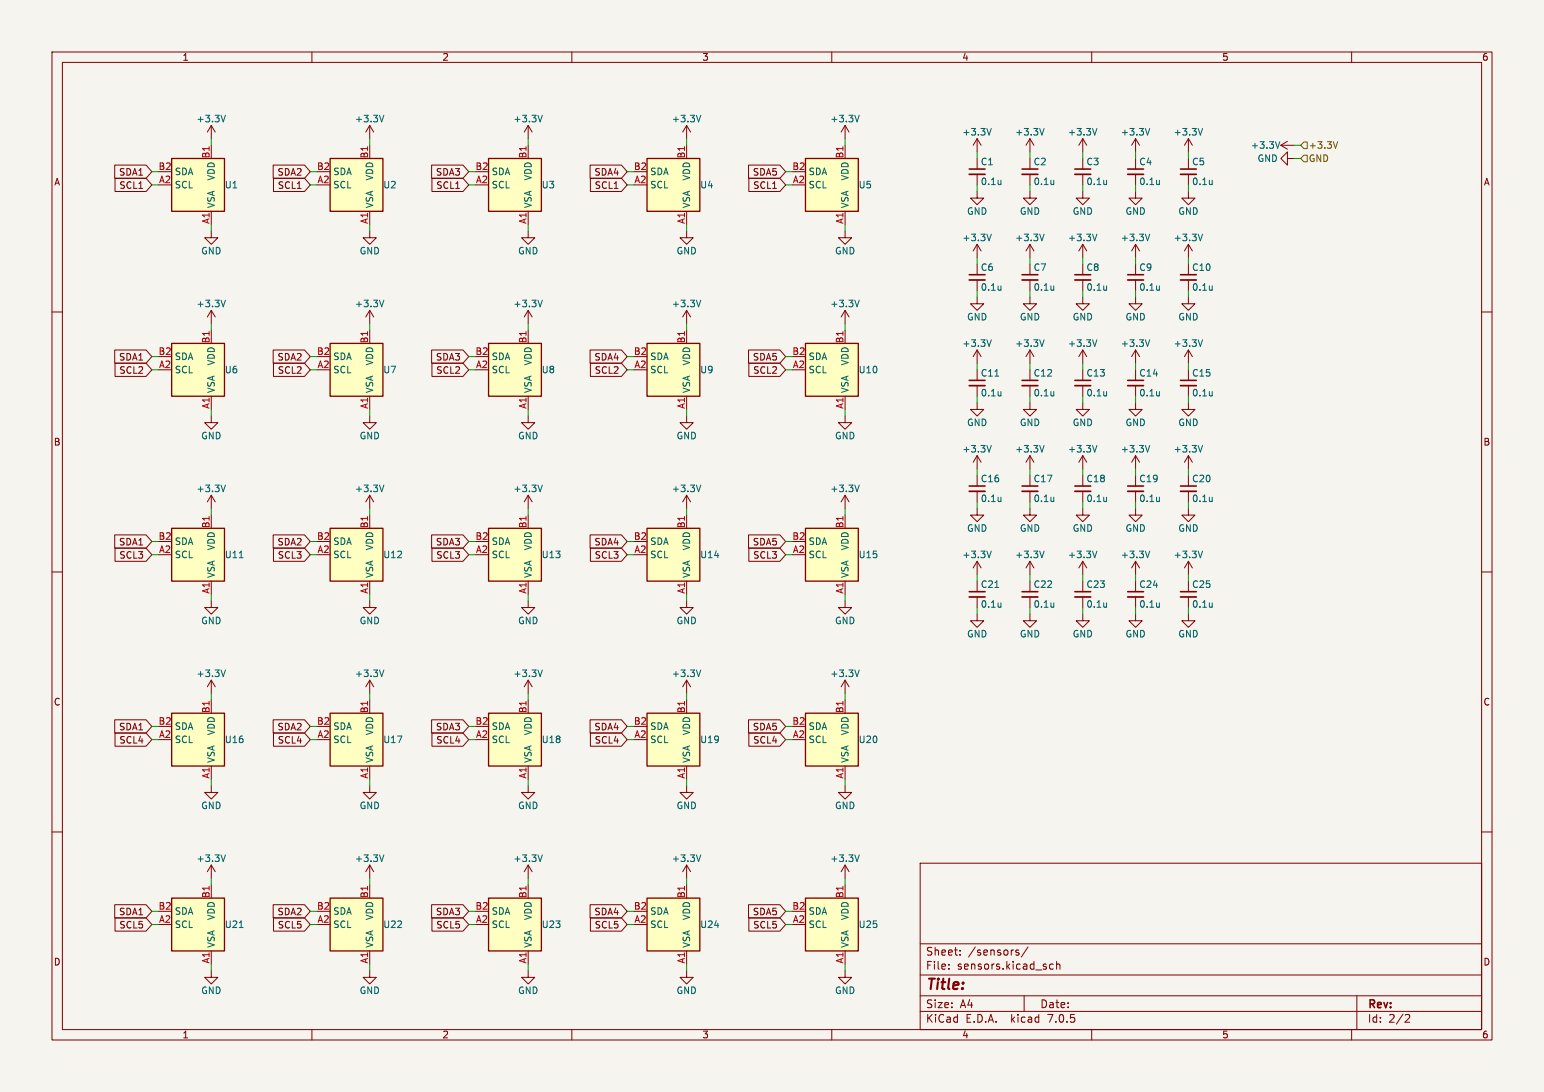
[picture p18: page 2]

Id: 2/2 Title: File: sensors.kicad_sch Sheet: /sensors/

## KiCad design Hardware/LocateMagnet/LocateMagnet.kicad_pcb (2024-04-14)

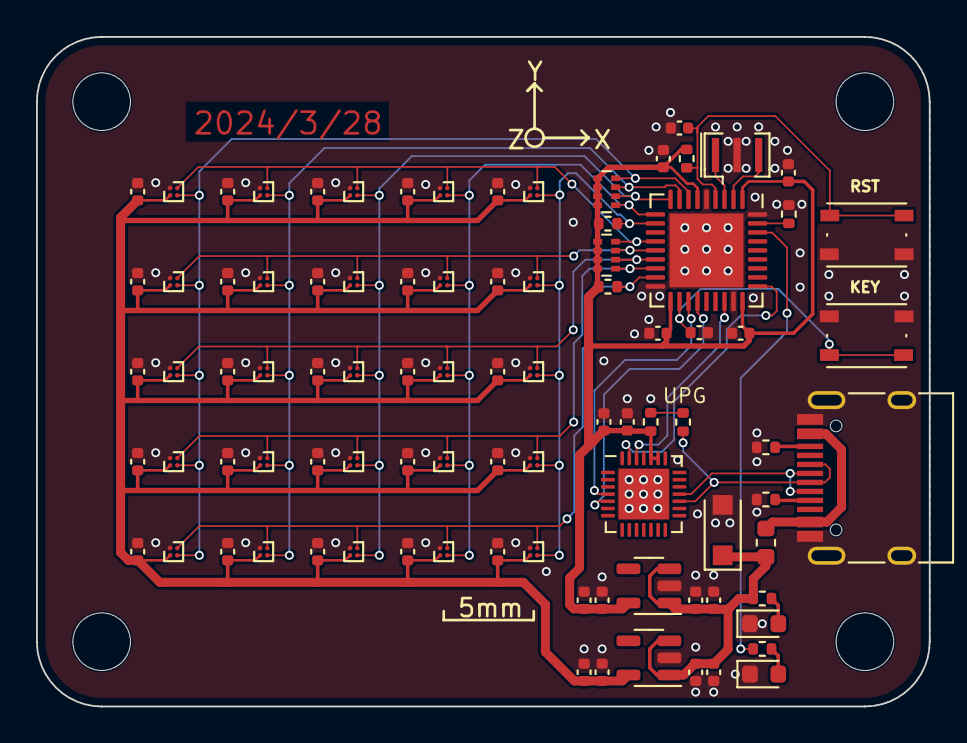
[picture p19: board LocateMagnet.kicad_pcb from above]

Board: 2 copper layers, 49.6 x 37.2 mm, 94 parts (0 on the bottom side), 32 nets.

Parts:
C1, C2, C3, C4, C5, C6, C7, C8, C9, C10, C11, C12, C13, C14, C15, C16, C17, C18, C19, C20, C21, C22, C23, C24, C25, C26, C28, C31, C32, C34, C35, C36, C37, C38, C39, C40, C41: 0.1u; C_0402_1005Metric
C27, C29, C30, C33: 10u; C_0402_1005Metric
D1: TVS 6V; D_SOD-123F
D2: LED-GREEN; LED_0603_1608Metric
D3: LED-RED; LED_0603_1608Metric
F1: 6V1A; Fuse_0603_1608Metric
H1, H2, H3, H4: MountingHole; MountingHole_3.2mm_M3
J2: USB_C_Receptacle_USB2.0; USB_C_Receptacle_HRO_TYPE-C-31-M-12
R1, R2, R3, R4, R5: 10K; R_0402_1005Metric
R6, R7: 5.1k; R_0402_1005Metric
R8, R9: 10k; R_0402_1005Metric
RN1, RN2: 4*10k; R_Array_Concave_4x0402
SW1: RST; SW_Push_1P1T_NO_Vertical_Wuerth_434133025816
SW2: KEY; SW_Push_1P1T_NO_Vertical_Wuerth_434133025816
TP1: TestPoint_2Pole; R_0402_1005Metric
U1, U2, U3, U4, U5, U6, U7, U8, U9, U10, U11, U12, U13, U14, U15, U16, U17, U18, U19, U20, U21, U22, U23, U24, U25: MMC5603NJ; WLP-4_0.83x0.83mm_P0.4mm
U26: CH549F; QFN-28-1EP_4x4mm_P0.4mm_EP2.8x2.8mm
U27: STM32F103TBUx; QFN-36-1EP_6x6mm_P0.5mm_EP4.1x4.1mm
U28, U29: RT9013-Lite; SOT-23-5
Y1: 3215-8MHz; Resonator_SMD_Murata_CSTxExxV-3Pin_3.0x1.1mm

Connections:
+3.3V: C1.1, C2.1, C3.1, C4.1, C5.1, C6.1, C7.1, C8.1, C9.1, C10.1, C11.1, C12.1, C13.1, C14.1, C15.1, C16.1, C17.1, C18.1, C19.1, C20.1, C21.1, C22.1, C23.1, C24.1, C25.1, C32.1, C33.1, U1.B1 (VDD), U2.B1 (VDD), U3.B1 (VDD), U4.B1 (VDD), U5.B1 (VDD), U6.B1 (VDD), U7.B1 (VDD), U8.B1 (VDD), U9.B1 (VDD), U10.B1 (VDD), U11.B1 (VDD), U12.B1 (VDD), U13.B1 (VDD), U14.B1 (VDD), U15.B1 (VDD), U16.B1 (VDD), U17.B1 (VDD), U18.B1 (VDD), U19.B1 (VDD), U20.B1 (VDD), U21.B1 (VDD), U22.B1 (VDD), U23.B1 (VDD), U24.B1 (VDD), U25.B1 (VDD), U29.5 (VOUT)
+3V3: C28.1, C29.1, C34.1, C35.1, C36.1, C37.1, C38.1, C39.1, R1.2, R2.2, R4.2, R5.2, RN1.1 (R1.1), RN1.2 (R2.1), RN1.3 (R3.1), RN1.4 (R4.1), RN2.1 (R1.1), RN2.2 (R2.1), RN2.3 (R3.1), RN2.4 (R4.1), U26.23 (VDD), U26.24 (V33), U27.1 (VDD), U27.6 (VDDA), U27.19 (VDD), U27.27 (VDD), U28.5 (VOUT)
+5V: C26.1, C27.1, C30.1, C31.1, D1.1 (K), F1.2, R9.1, U28.1 (VIN), U28.3 (EN), U29.1 (VIN), U29.3 (EN)
/DAP_RX: U26.4 (P3.0/RXD), U27.21 (PA9)
/DAP_TX: U26.5 (P3.1/TXD), U27.22 (PA10)
/KEY: C41.1, SW2.2, U27.20 (PA8)
/MCU_LED: R8.1, U27.34 (PB7)
/NRST: C40.1, R2.1, SW1.2, U27.4 (NRST)
/SWCLK: U26.27 (P1.4/SCS/UCC1/AIN4), U27.28 (PA14)
/SWDIO: U26.26 (P1.1/T2EX/CAP2/AIN1), U27.25 (PA13)
/USB_DM: J2.A7 (D-), J2.B7 (D-), U26.18 (P5.0/DM/UDM)
/USB_DP: J2.A6 (D+), J2.B6 (D+), TP1.1, U26.17 (P5.1/DP/UDP)
GND: C1.2, C2.2, C3.2, C4.2, C5.2, C6.2, C7.2, C8.2, C9.2, C10.2, C11.2, C12.2, C13.2, C14.2, C15.2, C16.2, C17.2, C18.2, C19.2, C20.2, C21.2, C22.2, C23.2, C24.2, C25.2, C26.2, C27.2, C28.2, C29.2, C30.2, C31.2, C32.2, C33.2, C34.2, C35.2, C36.2, C37.2, C38.2, C39.2, C40.2, C41.2, D1.2 (A), D2.1 (K), D3.1 (K), J2.A1 (GND), J2.A12 (GND), J2.B1 (GND), J2.B12 (GND), J2.S1 (SHIELD), R3.2, R6.2, R7.2, SW1.1, SW2.1, U1.A1 (VSA), U2.A1 (VSA), U3.A1 (VSA), U4.A1 (VSA), U5.A1 (VSA), U6.A1 (VSA), U7.A1 (VSA), U8.A1 (VSA), U9.A1 (VSA), U10.A1 (VSA), U11.A1 (VSA), U12.A1 (VSA), U13.A1 (VSA), U14.A1 (VSA), U15.A1 (VSA), U16.A1 (VSA), U17.A1 (VSA), U18.A1 (VSA), U19.A1 (VSA), U20.A1 (VSA), U21.A1 (VSA), U22.A1 (VSA), U23.A1 (VSA), U24.A1 (VSA), U25.A1 (VSA), U26.29 (GND), U27.5 (VSSA), U27.18 (VSS), U27.26 (VSS), U27.36 (VSS), U27.37 (VSS), U28.2 (GND), U29.2 (GND), Y1.2
unnamed: D2.2 (A), R8.2
unnamed: D3.2 (A), R9.2
unnamed: F1.1, J2.A4 (VBUS), J2.A9 (VBUS), J2.B4 (VBUS), J2.B9 (VBUS)
unnamed: J2.A5 (CC1), R7.1
unnamed: J2.B5 (CC2), R6.1
unnamed: R1.1, TP1.2
unnamed: R3.1, U27.35 (BOOT0)
unnamed: U27.2 (PD0), Y1.3
unnamed: U27.3 (PD1), Y1.1
SCL1: RN2.8 (R1.2), U1.A2 (SCL), U2.A2 (SCL), U3.A2 (SCL), U4.A2 (SCL), U5.A2 (SCL), U27.13 (PA6)
SCL2: RN2.7 (R2.2), U6.A2 (SCL), U7.A2 (SCL), U8.A2 (SCL), U9.A2 (SCL), U10.A2 (SCL), U27.14 (PA7)
SCL3: RN2.6 (R3.2), U11.A2 (SCL), U12.A2 (SCL), U13.A2 (SCL), U14.A2 (SCL), U15.A2 (SCL), U27.15 (PB0)
SCL4: RN2.5 (R4.2), U16.A2 (SCL), U17.A2 (SCL), U18.A2 (SCL), U19.A2 (SCL), U20.A2 (SCL), U27.16 (PB1)
SCL5: R5.1, U21.A2 (SCL), U22.A2 (SCL), U23.A2 (SCL), U24.A2 (SCL), U25.A2 (SCL), U27.17 (PB2)
SDA1: RN1.8 (R1.2), U1.B2 (SDA), U6.B2 (SDA), U11.B2 (SDA), U16.B2 (SDA), U21.B2 (SDA), U27.7 (PA0)
SDA2: RN1.7 (R2.2), U2.B2 (SDA), U7.B2 (SDA), U12.B2 (SDA), U17.B2 (SDA), U22.B2 (SDA), U27.8 (PA1)
SDA3: RN1.6 (R3.2), U3.B2 (SDA), U8.B2 (SDA), U13.B2 (SDA), U18.B2 (SDA), U23.B2 (SDA), U27.9 (PA2)
SDA4: RN1.5 (R4.2), U4.B2 (SDA), U9.B2 (SDA), U14.B2 (SDA), U19.B2 (SDA), U24.B2 (SDA), U27.10 (PA3)
SDA5: R4.1, U5.B2 (SDA), U10.B2 (SDA), U15.B2 (SDA), U20.B2 (SDA), U25.B2 (SDA), U27.11 (PA4)

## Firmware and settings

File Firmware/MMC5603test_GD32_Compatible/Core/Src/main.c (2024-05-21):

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
/* Includes ------------------------------------------------------------------*/
#include "main.h"
#include "dma.h"
#include "tim.h"
#include "usart.h"
#include "gpio.h"

/* USER CODE BEGIN Includes */
#include <stdio.h>
#include "math.h"
#include "I2C_SW.h"
#include <string.h>
#include <stdlib.h>
/* USER CODE END Includes */


/* USER CODE BEGIN PV */
int32_t sensorValBuffer[5][5][4] = {0}; // x,y,z,Mag
uint32_t errorVal[1000];
int parameterM;
int minIndex;
uint8_t totalTestBit = 1;
SWI2C sensorList[25]={
	{GPIOA,GPIO_PIN_6,GPIOA,GPIO_PIN_0},
	{GPIOA,GPIO_PIN_6,GPIOA,GPIO_PIN_1},
	{GPIOA,GPIO_PIN_6,GPIOA,GPIO_PIN_2},
	{GPIOA,GPIO_PIN_6,GPIOA,GPIO_PIN_3},
	{GPIOA,GPIO_PIN_6,GPIOA,GPIO_PIN_4},	

	{GPIOA,GPIO_PIN_7,GPIOA,GPIO_PIN_0},
	{GPIOA,GPIO_PIN_7,GPIOA,GPIO_PIN_1},
	{GPIOA,GPIO_PIN_7,GPIOA,GPIO_PIN_2},
	{GPIOA,GPIO_PIN_7,GPIOA,GPIO_PIN_3},
	{GPIOA,GPIO_PIN_7,GPIOA,GPIO_PIN_4},
	
	{GPIOB,GPIO_PIN_0,GPIOA,GPIO_PIN_0},
	{GPIOB,GPIO_PIN_0,GPIOA,GPIO_PIN_1},
	{GPIOB,GPIO_PIN_0,GPIOA,GPIO_PIN_2},
	{GPIOB,GPIO_PIN_0,GPIOA,GPIO_PIN_3},
	{GPIOB,GPIO_PIN_0,GPIOA,GPIO_PIN_4},
	
	{GPIOB,GPIO_PIN_1,GPIOA,GPIO_PIN_0},
	{GPIOB,GPIO_PIN_1,GPIOA,GPIO_PIN_1},
	{GPIOB,GPIO_PIN_1,GPIOA,GPIO_PIN_2},
	{GPIOB,GPIO_PIN_1,GPIOA,GPIO_PIN_3},
	{GPIOB,GPIO_PIN_1,GPIOA,GPIO_PIN_4},
		
	{GPIOB,GPIO_PIN_2,GPIOA,GPIO_PIN_0},
	{GPIOB,GPIO_PIN_2,GPIOA,GPIO_PIN_1},
	{GPIOB,GPIO_PIN_2,GPIOA,GPIO_PIN_2},
	{GPIOB,GPIO_PIN_2,GPIOA,GPIO_PIN_3},
	{GPIOB,GPIO_PIN_2,GPIOA,GPIO_PIN_4}

};

uint8_t txBuffer[1000];
/* USER CODE END PV */

void SystemClock_Config(void);
/* USER CODE BEGIN 0 */

// read who-am-i register
int testSensor(SWI2C sensorLabel){
	
	i2c_start(sensorLabel);
	i2c_send(sensorLabel,0x60); // Dummy Write 0x30 1
	if(i2c_wit_ack(sensorLabel)) printf("No ACK\n");
	i2c_send(sensorLabel,0x39);
	if(i2c_wit_ack(sensorLabel)) printf("No ACK\n");
	 
	delay_us(50);
	i2c_start(sensorLabel);
	i2c_send(sensorLabel,0x61); // Read 0x30 1
	if(i2c_wit_ack(sensorLabel)) printf("No ACK\n");
	uint8_t dataSent = i2c_read(sensorLabel);
	i2c_no_ack(sensorLabel);
	i2c_stop(sensorLabel);
	if(dataSent == 0x10) {
		//printf("Test Succcess\n");
		return 1;
	}
	return 0;
}

void sensorInit(SWI2C sensorLabel){
	//Enable Continuous mode 
	uint8_t dataByte = 0xff;
	i2cWriteByte(sensorLabel,0x60,0x1A,1,&dataByte);	// Write ODR 
	dataByte = 0xA0;
	i2cWriteByte(sensorLabel,0x60,0x1B,1,&dataByte);	// Write CR0
	dataByte = 0x10;
	i2cWriteByte(sensorLabel,0x60,0x1D,1,&dataByte);	// Write CR2
	
}

void readSensorData(SWI2C sensorLabel,uint32_t* dataBuf){
	uint8_t iicDataBuffer[32];
	i2cReadByte(sensorLabel,0x60,0x00,8,iicDataBuffer);
	dataBuf[0] = (uint32_t)iicDataBuffer[0] << 12 | (uint32_t)iicDataBuffer[1] << 4 |
      (uint32_t)iicDataBuffer[6] >> 4;
	dataBuf[1] = (uint32_t)iicDataBuffer[2] << 12 | (uint32_t)iicDataBuffer[3] << 4 |
      (uint32_t)iicDataBuffer[7] >> 4;
	dataBuf[2] = (uint32_t)iicDataBuffer[4] << 12 | (uint32_t)iicDataBuffer[5] << 4 |
      (uint32_t)iicDataBuffer[8] >> 4;
	dataBuf[0] -= (uint32_t)1<<19;
	dataBuf[1] -= (uint32_t)1<<19;
	dataBuf[2] -= (uint32_t)1<<19;
}

int fastAbs(int inputNum){
	return ((inputNum >> 31) | 1) * inputNum;
}
/* USER CODE END 0 */

/**
  * @brief  The application entry point.
  * @retval int
  */
int main(void)
{
  /* MCU Configuration--------------------------------------------------------*/

  /* Reset of all peripherals, Initializes the Flash interface and the Systick. */
  HAL_Init();

  /* Configure the system clock */
  SystemClock_Config();

  /* Initialize all configured peripherals */
  MX_GPIO_Init();
  MX_DMA_Init();
  MX_USART1_UART_Init();
  MX_TIM2_Init();
  MX_TIM1_Init();
  /* USER CODE BEGIN 2 */
	HAL_TIM_Base_Start(&htim1);
	HAL_TIM_Base_Start(&htim2);
  /* USER CODE END 2 */

  /* Infinite loop */
  /* USER CODE BEGIN WHILE */
	int TargetMagX,TargetMagY,TargetMagZ;	 
	int relativeX,relativeY,relativeZ;
	int minNum;
	for(int i=0;i<25;i++){
		if(testSensor(sensorList[i])==0){
			totalTestBit=0;
		}
	 }
	if(totalTestBit) 
		printf("25 Test Succcess\n");
	for(int i=0;i<25;i++)
		sensorInit(sensorList[i]);
	int testVal[3] = {0};
	int timeSpent;
  while (1)
  {
    /* USER CODE END WHILE */

    /* USER CODE BEGIN 3 */
	for(int i=0;i<25;i++){
		readSensorData(sensorList[i],(uint32_t*)sensorValBuffer[i/5][i%5]);
	}
	//uint8_t strLen = 
	sprintf((char *)txBuffer, "U %d %d %d %d %d %d %d %d %d %d %d %d %d %d %d %d %d %d %d %d %d %d %d %d %d\n"
														"V %d %d %d %d %d %d %d %d %d %d %d %d %d %d %d %d %d %d %d %d %d %d %d %d %d\n"
														"W %d %d %d %d %d %d %d %d %d %d %d %d %d %d %d %d %d %d %d %d %d %d %d %d %d\n",
														sensorValBuffer[0][0][0],sensorValBuffer[0][1][0],sensorValBuffer[0][2][0],sensorValBuffer[0][3][0],sensorValBuffer[0][4][0],
														sensorValBuffer[1][0][0],sensorValBuffer[1][1][0],sensorValBuffer[1][2][0],sensorValBuffer[1][3][0],sensorValBuffer[1][4][0],
														sensorValBuffer[2][0][0],sensorValBuffer[2][1][0],sensorValBuffer[2][2][0],sensorValBuffer[2][3][0],sensorValBuffer[2][4][0],
														sensorValBuffer[3][0][0],sensorValBuffer[3][1][0],sensorValBuffer[3][2][0],sensorValBuffer[3][3][0],sensorValBuffer[3][4][0],
														sensorValBuffer[4][0][0],sensorValBuffer[4][1][0],sensorValBuffer[4][2][0],sensorValBuffer[4][3][0],sensorValBuffer[4][4][0],
														sensorValBuffer[0][0][1],sensorValBuffer[0][1][1],sensorValBuffer[0][2][1],sensorValBuffer[0][3][1],sensorValBuffer[0][4][1],
														sensorValBuffer[1][0][1],sensorValBuffer[1][1][1],sensorValBuffer[1][2][1],sensorValBuffer[1][3][1],sensorValBuffer[1][4][1],
														sensorValBuffer[2][0][1],sensorValBuffer[2][1][1],sensorValBuffer[2][2][1],sensorValBuffer[2][3][1],sensorValBuffer[2][4][1],
														sensorValBuffer[3][0][1],sensorValBuffer[3][1][1],sensorValBuffer[3][2][1],sensorValBuffer[3][3][1],sensorValBuffer[3][4][1],
														sensorValBuffer[4][0][1],sensorValBuffer[4][1][1],sensorValBuffer[4][2][1],sensorValBuffer[4][3][1],sensorValBuffer[4][4][1],
														sensorValBuffer[0][0][2],sensorValBuffer[0][1][2],sensorValBuffer[0][2][2],sensorValBuffer[0][3][2],sensorValBuffer[0][4][2],
														sensorValBuffer[1][0][2],sensorValBuffer[1][1][2],sensorValBuffer[1][2][2],sensorValBuffer[1][3][2],sensorValBuffer[1][4][2],
														sensorValBuffer[2][0][2],sensorValBuffer[2][1][2],sensorValBuffer[2][2][2],sensorValBuffer[2][3][2],sensorValBuffer[2][4][2],
														sensorValBuffer[3][0][2],sensorValBuffer[3][1][2],sensorValBuffer[3][2][2],sensorValBuffer[3][3][2],sensorValBuffer[3][4][2],
														sensorValBuffer[4][0][2],sensorValBuffer[4][1][2],sensorValBuffer[4][2][2],sensorValBuffer[4][3][2],sensorValBuffer[4][4][2]);
	
	HAL_UART_Transmit_DMA(&huart1, txBuffer, strlen((char *)txBuffer));
	
	HAL_GPIO_TogglePin(LED_GPIO_Port, LED_Pin);
  }
  /* USER CODE END 3 */
}

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
/* USER CODE BEGIN 4 */
	int fgetc(FILE *f)
	{
	  uint8_t ch = 0;
	  HAL_UART_Receive(&huart1, &ch, 1, 0xffff);
	  return ch;
	}

	int fputc(int ch, FILE *f)
	{
	  HAL_UART_Transmit(&huart1, (uint8_t *)&ch, 1, 0xffff);
	  return ch;
	}
/* USER CODE END 4 */
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


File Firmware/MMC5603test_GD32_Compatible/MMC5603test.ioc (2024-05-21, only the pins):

Mcu.UserName=STM32F103TBUx
PA0-WKUP.Signal=GPIO_Output
PA1.Signal=GPIO_Output
PA10.Signal=USART1_RX
PA13.Signal=SYS_JTMS-SWDIO
PA14.Signal=SYS_JTCK-SWCLK
PA2.Signal=GPIO_Output
PA3.Signal=GPIO_Output
PA4.Signal=GPIO_Output
PA6.Signal=GPIO_Output
PA7.Signal=GPIO_Output
PA9.Signal=USART1_TX
PB0.Signal=GPIO_Output
PB1.Signal=GPIO_Output
PB2.Signal=GPIO_Output
PB6.Signal=GPIO_Input
PB7.GPIO_Label=LED
PB7.Signal=GPIO_Output
PD0-OSC_IN.Signal=RCC_OSC_IN
PD1-OSC_OUT.Signal=RCC_OSC_OUT

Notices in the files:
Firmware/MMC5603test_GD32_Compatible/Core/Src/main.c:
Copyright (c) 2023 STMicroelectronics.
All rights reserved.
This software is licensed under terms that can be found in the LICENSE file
